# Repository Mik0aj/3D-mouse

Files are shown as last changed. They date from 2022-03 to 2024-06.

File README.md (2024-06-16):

# Synopsis

The aim of this project is to develop a prototype for a practical device designed to expedite the process of designing 3D models in CAD (Computer-Aided Design) software. The device is intended to allow users to freely rotate the camera across six axes. Commercial solutions currently available in the market are often expensive. The motivation behind this work is to create an affordable alternative that leverages easily accessible modules such as gyroscopes and accelerometers. To achieve movement across the XYZ axes, parametric plastic springs are utilized as compliant elements.
### Showcase video:
https://www.youtube.com/watch?v=9irIqQizjRs&t=3s

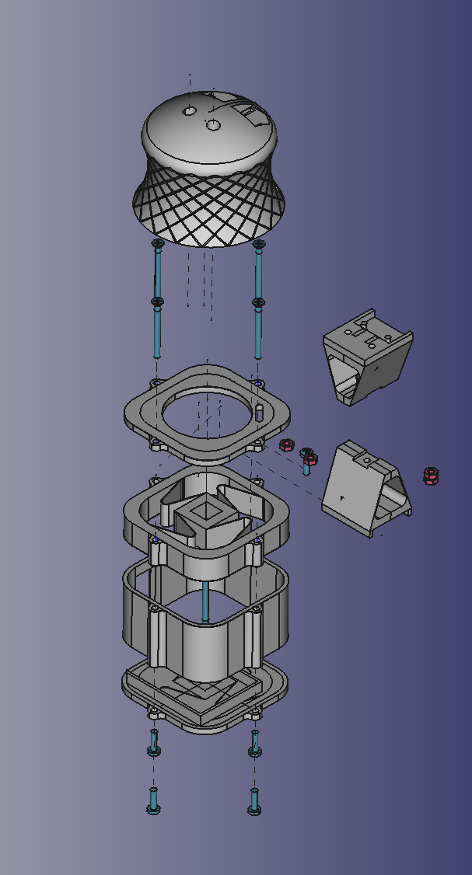
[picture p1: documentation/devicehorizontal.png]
"Exploaded view"


# Software 
## Design Patterns
Design patterns are best practices in software design aimed at enhancing code quality, efficiency, and reusability. This section outlines the design patterns utilized in this project, explaining their application to improve understanding. The implementations are based on references from established literature.

### Protothreads
Protothreads are lightweight, threads typically used in embedded systems where resources are limited, and multitasking is essential. Despite their simplicity, they provide effective concurrency in projects involving multiple sensors. Since the Arduino controller is single-threaded, protothreads simulate multitasking by sequentially executing code within a single thread using precise timing between function calls.

Usage in Project:

* protothreadMpuUpdate: Manages continuous reading of values from the gyroscope (MPU6050).
* protothreadJoystickBroadcast: Decides whether device should emulate a HID device in current moment.
* protothreadRGB: Provides visual feedback.
* protothreadPrintSerial: Displays key device parameters.
Each protothread interacts with an enum class Mode reference to determine the device's state and adjusts its behavior accordingly, similar to a Moore machine using switch statements.

### Adapter Pattern
The adapter pattern allows different libraries with varying interfaces to work together by converting incompatible interfaces into a compatible one. This is particularly useful in integrating different HID libraries that have different methods for similar functionalities.

Usage in Project:

* Created an interface JoystickEmulator.
* Developed adapters for XInput and Joystick libraries, enabling them to interact through a unified interface.
This pattern ensures flexibility in choosing the best library without necessitating significant code changes.

### Watchdog Pattern
The watchdog pattern enhances system reliability by monitoring the system for malfunctions and performing corrective actions like system resets if a failure is detected.

Usage in Project:

* Implemented a watchdog timer to monitor system health.
* Used deviceFailed() to handle errors, generate user feedback, and reset the device if necessary.
Error Codes:

* 1: Initialization failure of MPU6050.
* 2: Problem reading from the Digital Motion Processor (DMP).
* 10: State machine received an invalid value.
This mechanism helps maintain system stability by automatically recovering from failures.

These design patterns collectively improve the robustness, maintainability, and functionality of the device, ensuring it meets the project requirements effectively.

# Model creation
Whole project utilizes the FreeCad modeling software and various modules it provides such as:
* techdraw
* FEM
* Part Design
* Spreadsheet
* Assembly

## Parametric modeling

3D model parameterization in CAD software involves defining and controlling various parameters and properties of the model that affect its shape, size, proportions, appearance, and other characteristics. This allows for easy customization and modification of the model while maintaining its geometric and structural dependencies. Parameterization of 3D models in CAD software provides greater flexibility and control over the design. Changes to parameters can be easily implemented, and models can be adapted to different requirements. Parameterization also allows for automated generation of model variants and facilitates iterative design modifications, which can accelerate the prototyping process and increase work efficiency.

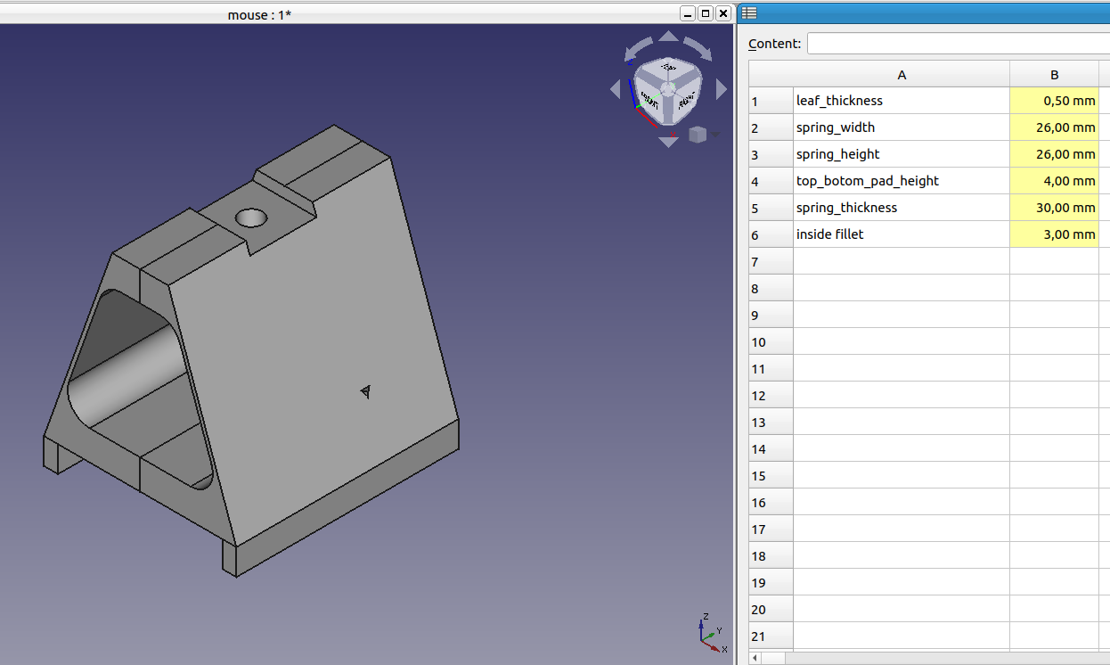
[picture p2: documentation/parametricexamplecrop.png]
"Parametric design"


## Fem simulations
The project utilizes Finite Element Method (FEM) simulations, performed using FreeCAD, to analyze and simulate the behavior of 3D models under various loads. FEM is a widely adopted numerical technique in engineering, used to model and analyze the behavior of different structures, including mechanical components. In this project, FEM is employed to verify the performance of compliant elements.

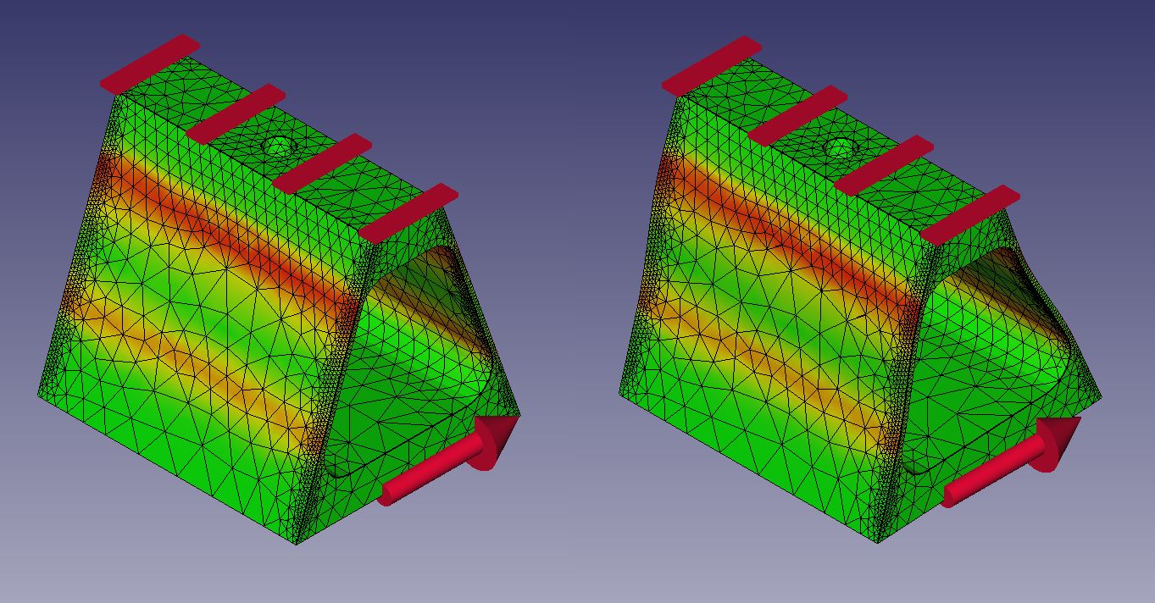
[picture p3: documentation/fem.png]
"FEM simulation"


## Hardware Components
* Arduino Pro Micro: This microcontroller board is based on the ATmega32u4 chip and is used to control the mouse's movements and buttons.
* MPU-6050 Sensor: This is a 6-axis gyro and accelerometer module that detects the device's orientation and acceleration.
* Two Buttons: These buttons are used to provide additional input to the device.

## 3D Printed Compliant Mechanisms:
These mechanisms are designed using springs that provide a tactile feedback to the user.
Software Components
The software for the 3D mouse is written in Arduino's programming language and is used to read the sensor data, control the device's movements, and process the button input.

## Setup and Usage
To use the 3D mouse, connect the Arduino Pro Micro and the MPU-6050 sensor to your computer. Then, upload the provided code to the Arduino board. The mouse can be used in any application that supports 6 DOF input, such as 3D modeling software or video games.

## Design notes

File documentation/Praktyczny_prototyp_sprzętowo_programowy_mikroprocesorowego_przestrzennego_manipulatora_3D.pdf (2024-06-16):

Uniwersytet Zielonogórski

Wydział Informatyki, Elektrotechniki i Automatyki

## Praca dyplomowa

## Kierunek: Informatyka

Praktyczny prototyp

sprzętowo-programowy

mikroprocesorowego przestrzennego

manipulatora 3D

## Mikołaj Mosoń

Promotor:
dr inż. Łukasz Hładowski

Zielona Góra, luty 2024

# Spis treści

1. Wstęp | 1
2. Implementacja | 3
3. Kontroler urządzenia | 20
4. Instrukcja obsługi | 23
5. Wnioski | 32

iv | Spis treści
A. Schematy urządzenia | 40

# Spis rysunków

2.1. Zrzut ekranu przedstawiajacy zastosowanie parametryczności w pro-
gramie FreeCAD | | 6
2.2. Zrzut ekranu przedstawiajacy symulacje FEM w programie FreeCAD. | 6
2.3. Poprawne dobranie parametrów wydruku | | 8
2.4. Niepoprawne dobranie parametrów wydruku | | 8
2.5. Zrzut ekranu przedstawiający najsłabsze punkty modelu, oraz przy-
kład brim | 8
2.6. Zrzut ekranu przedstawiający rezultat testów jednostkowych w VsCode. 19
4.1. Zrzut ekranu przedstawiający ułożenie sprężyn wewnątrz urządzenia
FreeCAD | 24
4.2. Zrzut ekranu przedstawiający w pełni rozłożone urządzenie w progra-
mie FreeCAD | 25
4.3. Krok pierwszy procesu składania urządzenia | 26
4.4. Krok drugi procesu składania urządzenia | 26
4.5. Krok trzeci procesu składania urządzenia | 27
4.6. Krok czwarty procesu składania urządzenia | 28
4.7. Krok piąty procesu składania urządzenia | 29
4.8. Krok szósty procesu składania urządzenia | 30
4.9. Schemat podłączenia urządzenia | 31

# Spis tabel

3.1. Porównanie Arduino Leonardo, STM32F103C8T6, ESP-WROOM-32
i Teensy-LC | 21

# Rozdział 1

# Wstęp

## 1.1. Cel i zakres pracy

Celem pracy jest opracowanie prototypu praktycznego urządzenia które, przyspieszy proces projektowania modeli 3D w programach typu CAD. Urządzenie ma za zadanie pozwolić użytkownikowi na swobodne obracanie kamerą w 6 osiach. Komercyjne rozwiązania dostępne aktualnie na rynku są drogie. Motywacją pracy jest stworzenie taniej alternatywy, która wykorzysta łatwo dostępne gotowe moduły żyroskopu i akcelerometru. Aby uzyskać ruch w osiach XYZ wykorzystane są elementy podatne w postaci parametrycznych plastikowych sprężyn.
Praca swym zakresem obejmuje:
- Opracowanie i praktyczne wykonanie układu elektronicznego dla manipulatora
- Opracowanie projektu i wykonanie modelu zewnętrznego dla manipulatora
- Projekt i implementacja oprogramowania umożliwiającego działanie urządzenia
- Wykonanie testów praktycznych opracowanego przyrządu

## 1.2. Analiza rynku

Rynek w tym przypadku to głównie zbiór klientów, którzy byliby zainteresowani wdrożeniem rozwiązania pozwalającego na zwiększenie komfortu oraz przyspieszenie projektowania w programach CAD. Możemy rozróżnić dwa główne typy klientów: klienci biznesowi, czyli centra inżynieryjne oraz klientów indywidualnych. Centra inżynieryjne - są to miejsca w których często projektuje się linie produkcyjne. Przykładem może być dostosowywanie paletek przewożących produkt na taśmociągu produkcyjnym. Klienci indywidualni - urządzenie mogłoby znaleźć swoje zastosowanie jako akcesorium dla freelancerów. Kolejną potencjalną grupą odbiorców indywidualnych byłyby osoby zajmujące się hobbistycznym modelowaniem 3D. Z racji zasady działania urządzeń takich jak joystick lub pad komputerowy, urządzenie mogłoby potencjalnie znaleźć swoje zastosowanie jako akcesorium dla graczy.

2 | Wstęp

## 1.3. Potrzeba biznesowa

| Obecnie rynek urządzeń wskazujących dla programów CAD zmonopolizowany
jest przez jedną firmę - 3Dconnexion. Inne urządzenia które byłyby w stanie wypełnić tę lukę wymagają skomplikowanej konfiguracji aby działać. Urządzenie opisywane w niniejszej pracy ma na celu stanowić tańszą alternatywę. Dodatkową zaletą jest bezproblemowa współpraca opracowanego narzędzia z systemem Linux. Należy podkreślić, iż rozwiązania opracowane przez firmę 3DConnection nie wspierają oficlajnie tego systemu.

## 1.4. Przegląd rozwiązań

Aktualnie na rynku dostępne są następujące typy urządzeń wejściowych:

| • Trackball[1] - urządzenie polegające na poruszaniu kulą zamiast poruszaniem
całym urządzeniem, jak w przypadku myszy.
| • Joystick[2], w zależności od modelu posiadają 2 lub 3 osie. Bez zewnętrznego
oprogramowania nie są wspierane przez oprogramowanie CAD.
| • 3DConnexion SpaceMouse[3] - to urządzenie do obsługi oprogramowania CAD, które umożliwia precyzyjne i sterowanie kursorami w aplikacjach 3D. Jest to

urządzenie typu "joystick" z 6-osiową kontrolą ruchów.

| • Steam controller[4] - urządzenie zaprojektowane z myślą o graniu na kom- puterze. Jednak oprogramowanie które jest do niego dołączone pozwala na skonfigurowanie go tak aby działał z każdą aplikacją. Posiada wbudowany

żyroskop oraz zestaw trackballi i joysticków.

# Rozdział 2

# Implementacja

## 2.1. Wykorzystane technologie

W tej sekcji zostaną omówione narzędzia, które zostały wykorzystane do realizacji projektu. Wśród tych narzędzi znajdują się m.in. oprogramowanie, drukarka 3D, komponenty elektroniczne, filament do drukarki oraz wiele innych. Wybór tych konkretnych narzędzi był wynikiem ich dostępności i przydatności w kontekście projektu oraz doświadczeniem przed rozpoczęciem projektu.

### 2.1.1. Oprogramowanie

- Arduino IDE[5] - narzędzie wykorzystywane w początkowej fazie projektu. Jednym z powodów wyboru Arduino IDE do programowania projektu było to, że jest to darmowe środowisko programistyczne. Ponadto, projekt wykorzystywał płytkę Arduino Leonardo, która była obsługiwana przez IDE. Ale wraz z rozwojem pojawiła się potrzeba bardziej zaawansowanych narzędzi do programowania i debugowania. W związku z tym środowisko programistyczne zostało zmienione.
- VsCode[6] - Wraz z rozwojem projektu podjęta została decyzja o zmianie środowiska programistycznego z Arduino IDE na VsCode. Rozważano również edytor tekstu NVIM, jednak pojawiły się problemy z konfiguracją serwera języków, aby był on kompatybilny z bibliotekami Arduino. Ostatecznie wybrano VsCode, ponieważ oferuje on większą funkcjonalność nie tracąc na prostocie użytkowania.
- PlatformIO[7] - to zaawansowane, open-source’owe środowisko programistyczne dla mikrokontrolerów, które umożliwia rozwijanie aplikacji dla różnych platform sprzętowych. Jest to uniwersalne narzędzie, które pozwala na pracę z różnymi platformami sprzętowymi, takimi jak Arduino, ESP8266, ESP32, STM32, oraz wiele innych. PlatformIO oferuje dostęp do tych samych bibliotek co Arduino IDE. Funkcje PlatformIO połączone wraz z frameworkiem Google Test pozwalają na testy jednostkowe oraz kompilację i weryfikacje części kodu na komputerze bez potrzeby przesyłania kodu na mikrokontroler.
- FreeCAD[8] - został wybrany do projektu z kilku powodów. Przede wszyst-

4 | Implementacja

kim, jest to darmowe oprogramowanie. Dodatkowo, FreeCAD posiada szereg narzędzi, które pozwalają na projektowanie modeli 3D oraz testowanie ich za pomocą metody FEM (Finite Element Method). Jednym z ważnych aspektów FreeCAD jest to, że modele, które się tworzy, mogą być parametryczne. Oznacza to, że po stworzeniu modelu, można go modyfikować, zmieniając wartości parametrów, takich jak długość, szerokość, wysokość itp. To bardzo przydatne na etapie prototypowania, pozwala to na osiągniecie wielu wariantów tego samego modelu. Ponadto, dzięki rozszerzeniom stworzonym przez społeczność, FreeCAD pozwala na składanie modeli w oprogramowaniu bez konieczności drukowania w celu sprawdzenia czy części do siebie pasują. Dzięki temu można zaoszczędzić czas i koszty związane z drukowaniem i testowaniem wielu wersji prototypu.

- Cura[9] - to darmowy, otwartoźródłowy program do przygotowywania plików do wydruku dla drukarek 3D. Dzięki Cura użytkownicy mogą dostosować ustawienia drukowania do swoich potrzeb, takie jak rozdzielczość, prędkość drukowania, ilość wypełnienia modelu i wiele innych. Cura oferuje także symulację druku, co pozwala na wczesne wykrywanie błędów i uniknięcie nieudanych prób drukowania. Sprawdzenie wyżej wymienionych parametrów jest krytycznie ważne w celu poprawnego wydruku elementów odkształcalnych.

### 2.1.2. Narzędzia

- Drukarka 3D tevo tornado[10] - wraz z zestawem części między innymi dyszami o różnych średnicach. Jest to drukarka typu FDM oparta na konstrukcji CR-10. W porównaniu do innych drukarek jak na przykład Prusa i3 MK3S lub Anycubic i3 Mega, Tevo Tornado posiada dużą przestrzeń roboczą o wymiarach 300 x 300 x 400 mm. Co z kolei niwelowało problem dzielenia modeli na mniejsze części oraz pozwalało na wydruk wielu modeli jednocześnie.
- Prusament PLA firmy Prusa Polymers[11] - wybór filamentu był kwestią bardzo ważną. Firma Prusa udostępnia parametry tego filamentu do pobrania[12], co pozwoliło na precyzyjne określenie jego właściwości i wykorzystanie ich w symulacjach numerycznych (FEM).

### 2.1.3. Biblioteki

- Google Test[13] - framework do testowania jednostkowego w języku C++, opracowany przez Google. Umożliwiający pisanie testów jednostkowych do weryfikacji poprawności zachowania kodu. Jest wyposażony w funkcje do odkrywania, wykonywania i raportowania wyników testów. Google Test wyposażone jest również w Google Mock (gmock). Pozwala to na prostsze testowanie skomplikowanych systemów, izolując poszczególne komponenty i sprawdzając ich interakcje z innymi częściami kodu.
- Spacenavd[14] - jest to sterownik umożliwiający komunikację pomiędzy urządzeniami typu myszy 3D a oprogramowaniem CAD. Jest w pełni kompatybilny z oprogramowaniem 3DConnexion, i jest jego darmową alternatywą. Oznacza

Modelowanie | 5

to że urządzenia współdziałające z tym sterownikiem powinny działać z ponad 200 programami wymienionymi na stronie 3DConnexion.

### 2.1.4. Elementy odkształcalne

Tradycyjnie aby uzyskać zakres ruchu w projektowanym urządzeniu stosowane są elementy sztywne (przykład stanowią zawiasy w drzwiach). Przeciwieństwem takich mechanizmów są elementy odkształcalne. Elementami odkształcalnymi są jednostki, które są częścią większej całości i są w stanie zmieniać swoje kształty i rozmiary w reakcji na siły mechaniczne, takie jak nacisk, rozciąganie lub skręcanie. Elementy odkształcalne są powszechnie stosowane w inżynierii i są istotne w projektowaniu i analizie konstrukcji, takich jak mosty, budynki, maszyny i sprzęt. Mogą być wykonane z różnych materiałów, takich jak stali, aluminium czy tworzywa sztuczne.

## 2.2. Modelowanie

W projekcie zastosowano technikę modelowania twardo powierzchniowego (z ang. hard surface) z parametryzacją modeli. Parametryzacja modeli 3D w programach CAD polega na definiowaniu i kontrolowaniu różnych parametrów i właściwości modelu, które wpływają na jego kształt, rozmiar, proporcje, wygląd i inne cechy. Pozwala to na łatwe dostosowywanie i modyfikowanie modelu, zachowując przy tym jego zależności geometryczne i konstrukcyjne. Dzięki parametryzacji modeli 3D w programach CAD uzyskuje się większą elastyczność i kontrolę nad projektem. Zmiany w parametrach mogą być łatwo wprowadzane, a modele mogą być dostosowywane do różnych wymagań. Parametryzacja pozwala również na automatyzację generowania wariantów modeli i ułatwia iteracyjne modyfikowanie projektu, co może przyspieszyć proces prototypowania i zwiększyć efektywność pracy. Sprężyny zostały wymodelowane na podstawie książki [15].
Dodatkową zaletą parametryzowanych sprężyn jest możliwość spersonalizowania urządzenia, dzięki czemu użytkownik może wybrać czy chce aby stawiały one mniejszy lub większy opór.

### 2.2.1. Symulacje FEM

Symulacje w oparciu o technikę elementów skończonych (Finite Element Method) w programie FreeCAD są narzędziem do analizy i symulacji zachowania modeli 3D pod wpływem obciążeń. FEM jest popularną metodą numeryczną wykorzystywaną w inżynierii do modelowania i analizy zachowania się różnych struktur, takich jak elementy mechaniczne. Metoda ta jest wykorzystywana w projekcie do sprawdzenia poprawności zachowania się elementów odkształcalnch. Moduł FEM, który umożliwia wygenerowanie odpowiedniej siatki modelu i przypisanie jej właściwości materiałowych. Właściwości materiałowe PLA zostały przypisane na podstawie parametrów technicznych podanych przez producenta filamentu[12].
Warto zwrócić uwagę że rys. 2.2 oraz 2.1 mogą wydawać się tym samym modelem. Jednakże do wykonania symulacji FEM wykorzystany został model uproszczony. Dla modelu ze zrzutu 2.1 możnaby wytworzyć siatkę potrzebną do symulacji ale trwałoby

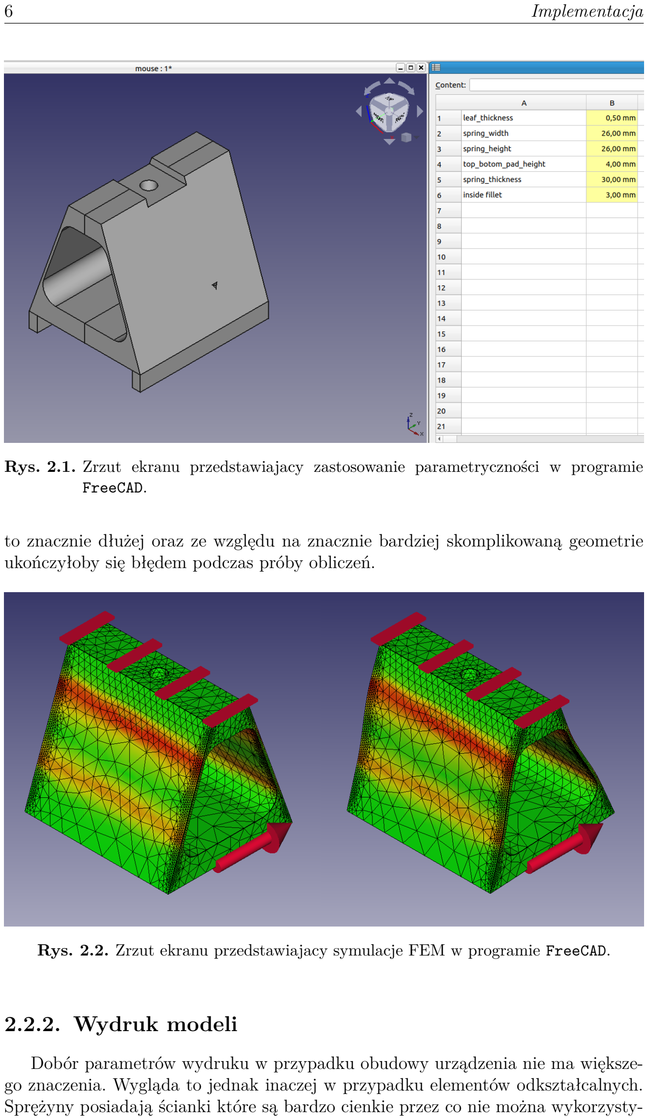
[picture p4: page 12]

6 | Implementacja

Rys. 2.1. Zrzut ekranu przedstawiajacy zastosowanie parametryczności w programie FreeCAD.

to znacznie dłużej oraz ze względu na znacznie bardziej skomplikowaną geometrie ukończyłoby się błędem podczas próby obliczeń.

Rys. 2.2. Zrzut ekranu przedstawiajacy symulacje FEM w programie FreeCAD.

### 2.2.2. Wydruk modeli

Dobór parametrów wydruku w przypadku obudowy urządzenia nie ma większego znaczenia. Wygląda to jednak inaczej w przypadku elementów odkształcalnych. Sprężyny posiadają ścianki które są bardzo cienkie przez co nie można wykorzysty-

Modelowanie | 7

wać ustawień takich jak brim. Brim to dodatkowa warstwa materiału na obrzeżach obiektu, która zapewnia lepszą przyczepność do stołu drukującego. Przykład zaznaczono kolorem niebieskim na rys. 2.5.
W celu utrzymania modelu w miejscu podczas wydruku najlepiej zastosować taśmę dwustronną lub klej. Rys. 2.3 przedstawia poprawnie wygenerowany g-code w programie cura. G-code jest to zestaw instrukcji które drukarka 3D musi wykonać w celu utworzenia modelu. Należy zwrócić uwagę że zewnętrzne cienkie ścianki sprężyny drukowane są jedną linią. Efekt ten można uzyskać dostosowując parametr leaf thickness widoczny na rys. 2.1 do szerokości linii wdruku. Najlepiej by te wartości były takie same jak średnica dyszy w drukarce 3D. Jest to najbardziej optymalne podejście do drukowania modelu ponieważ jest on wtedy najbardziej wytrzymały. Na rys. 2.3 oraz 2.5 widać białe punkty. Każda warstwa posiada dwa takie punkty i oznaczają one miejsce startowe oraz końcowe. W figurze z poprawnie dobranymi parametrami można zauważyć że punkty rozmieszczone są w losowy sposób. Losowość ta wraz z dodatkowym zastosowaniem zaokrąglenia (ang. fillet) wewnątrz modelu sprawia że wydruk jest wytrzymalszy niż to co zostałoby uzyskane w przypadku który widać na 2.5. Rys. 2.5 niemalże wszystkie punkty startowe w tym samym miejscu modelu. Podczas wydruku powoduje to nagromadzenie PLA w tych miejscach przez co ścianka sprężyny nie zawsze prawidłowo przylega poprawnie do reszty modelu. Staje się to najsłabszym miejscem uzyskanej bryły i w praktyce to będzie miejsce które pęknie jako pierwsze.
W przypadku rys. 2.4 w miejscu ścianki sprężyny wygenerowane zostało wypełnienie które widać za pomocą koloru pomarańczowego. Tak krótkie linie mają problem z adhezją do poprzednich warstw. Prowadzi to do niestabilności, słabej jakości wydruku oraz nierównomiernej ekstruzji plastiku. A w skrajnych przypadkach powoduje zacięcie się drukarki.
W celu zwiększenia komfortu gałka urządzenia posiada ergonomiczny kształt tak by użytkownik mógł ją wygodnie chwycić. Wygładzona powierzchnia urządzenia powoduje, że użytkownik ma trudności z pewnym chwytem. Potencjalnym rozwiązaniem jest zapożyczenie techniki wywodzącej się z obsługi tokarki zwaną radełkowaniem widoczną na zrzucie 4.2. Na gałce urządzenia został wytworzony wzór przypominający diamenty. Wytworzenie wzoru polega na ekstrudowaniu dwóch przecinających się linii i powielaniu wzoru z przesunięciem o kilka stopni. Jest to operacja bardzo wymagająca obliczeniowo dla komputera, i zajmuje więcej czasu w zależności od ilości powtórzeń. Ponieważ FreeCAD przy każdej modyfikacji modelu ponownie przelicza wszystkie kroki tą operacje najlepiej zastosować na samym końcu hierarchii. W przeciwnym razie najmniejsza nawet zmiana może potrwać do kilku minut.

### 2.2.3. Problem nazewnictwa topologicznego

Problem z nazewnictwem topologicznym w programie FreeCAD polega na tym, gdy po wprowadzeniu zmian w obiekcie, takie jak wyciągnięcie, wycięcie, połączenie itp., wewnętrzna nazwa kształtu może ulec zmianie. Ta zmiana może wpłynąć na inne parametryczne właściwości zależne od tego kształtu. Skutkiem tego błędu może być na przykład przypisanie szkicu do innej ściany. Jest to zjawisko który dotyczy wszystkich modeli tworzonych za pomocą programu FreeCAD. Problem można zniwelować stosując odpowiednie techniki omówione w dokumentacji programu [16].

8 | Implementacja

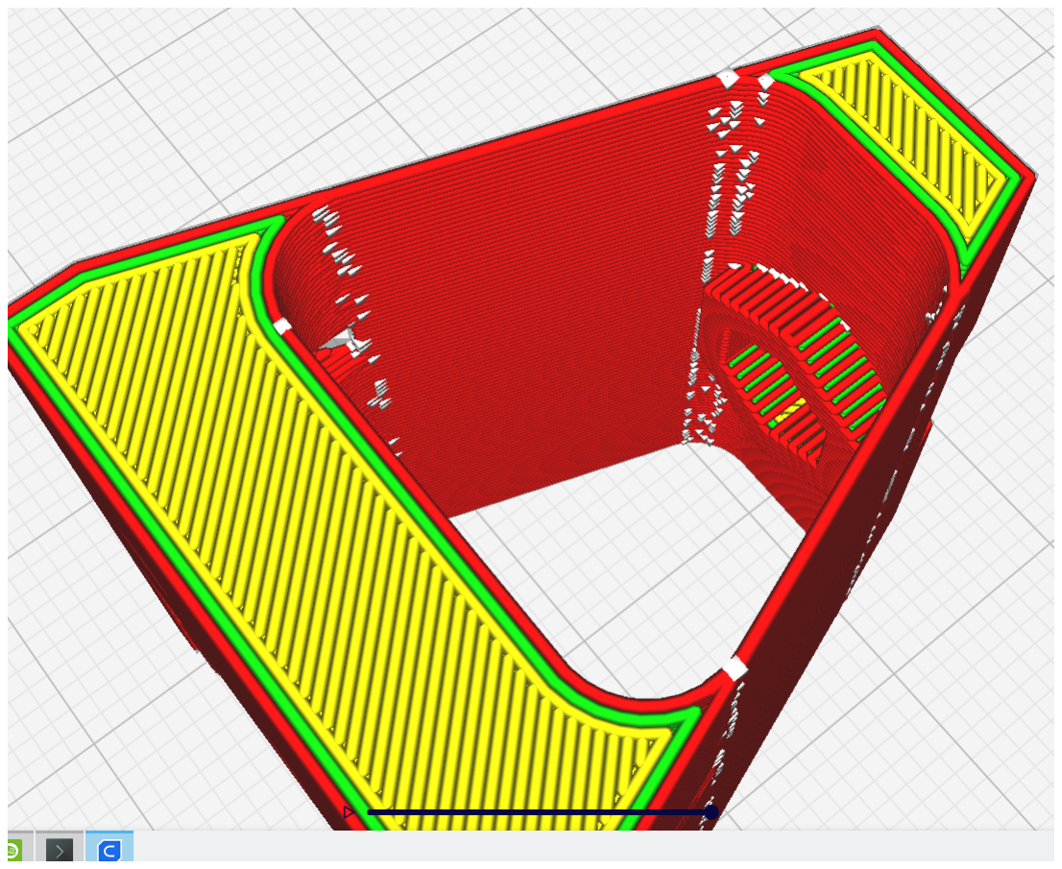
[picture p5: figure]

Rys. 2.3. Poprawne dobranie parametrów wydruku.

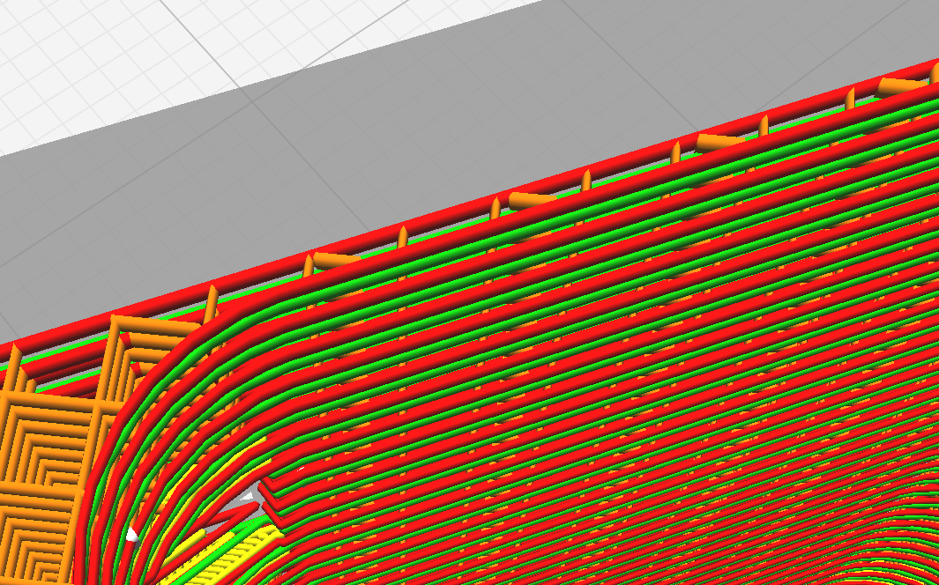
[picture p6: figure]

Rys. 2.4. Niepoprawne dobranie parametrów wydruku.

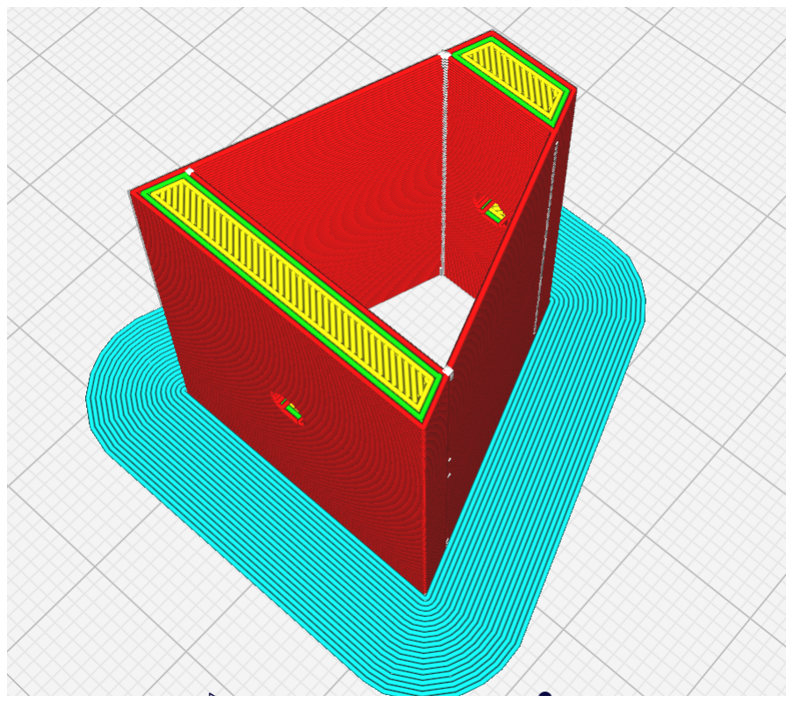
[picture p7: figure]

Rys. 2.5. Zrzut ekranu przedstawiający najsłabsze punkty modelu, oraz przykład brim.

Wzorce projektowe | 9

## 2.3. Wzorce projektowe

Wzorce projektowe są uważane za najlepsze praktyki projektowania, które mają na celu zwiększenie jakości, wydajności i ponownego wykorzystywania kodu źródłowego.
W tej sekcji zostaną przedstawione wybrane wzorce projektowe wykorzystane w ramach realizacji projektu. Przedstawione zostaną opisy i przykłady zastosowań tych wzorców w celu zwiększenia zrozumienia ich roli. Wykorzystane w pracy implementacje wzorców projektowych bazują na książkach [17] i [18].

### 2.3.1. Protowątki

Protowątki są zwykle używane w systemach wbudowanych, gdzie zasoby są ograniczone, a wymagane jest jednoczesne wykonywanie wielu zadań. Dzięki prostocie i efektywności, są często stosowane w projektach do obsługi urządzeń wielu sensorów. Arduino jest kontrolerem jednoprocesorowym i jednowątkowym. Oznacza to że jedynym sposobem na uzyskanie złudzenia wielozadaniowości jest zastosowanie protowątków.
Protowątki opierają się na technice opakowywania kodu w funkcje, które mogą być wykonywane sekwencyjnie w ramach jednego wątku. Działają one dzięki precyzyjnemu odmierzaniu czasu jaki upłynął pomiędzy kolejnymi wykonaniami funkcji. W celu zwiększenia czytelności kodu jeden wątek zajmuje się tylko jednym zadaniem. W projekcie zostały zastosowane 4 protowątki:
- protothreadMpuUpdate - odpowiedzialny za kolejne odczytywanie wartości z czujnika żyroskopu (MPU6050),
- protothreadJoystickBroadcast - stosowany za emulację urządzenia HID,
- protothreadRGB - wątek zastosowany w celu wizualnej informacji zwrotnej,
- protothreadPrintSerial - jest to wątek który wyświetla najważniejsze parametry urządzenia,

Do każdego z protowątków za pomocą referencji przekazywane są obiekty enum klasy Mode lst. 2.1. Jest to referencja typu const ponieważ wątki jedynie odczytują stan w jakim urządzenie aktualnie się znajduje.

1 | enum c l a s s Mode
2 | {
3 | XYZ,
4 | rXrYrZ ,
5 | BROADCASTING,
6 | NOT_BROADCASTING,
7 | } ;

Listing 2.1. Implementacja stanów w których urządzenie może sie znaleźć

Następnie na wzór automatu Moore’a (tzn kolejne stany urządzenia nie są zależne od poprzednich) dany protowątek za pomocą instrukcji switch decyduje jak powinien się zachować.

Implementacja

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

}
| PT_END(&protoThread ) ;

}

Listing 2.2. Protowątek odpowiedzialny za obsługę MPU6050

Funkcja na listingu 2.2 zajmuje się obsługą żyroskopu i akcelerometru. Urządzenie nieustannie zapisuje dane z żyroskopu i zapisuje je do dwukierunkowej kolejki. Gdy urządzenie nie znajduje się w trybie nadawania wartości te zapisywane są jako offsety. Ta potrzeba wynika z tego że gdy użytkownik obróci urządzenie gdy to nie znajduje się w trybie nadawania, wyniki będą przekłamane. Urządzenie musi się samo skorygować aby wysyłać poprawne sygnały. Dlatego wartości pomniejszane są o offsety i zapisywane do kontenera deviceValues, który wykorzystany wykorzystany
| jest w innych protowątkach 2.3.

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

Wzorce projektowe | 11
4 | PT_BEGIN(&protoThread ) ;
5 | w hil e ( 1 )
6 | {
7 | J o y s ti c k B r o a d c a s t = m i l l i s ( ) ;
8 | PT_WAIT_UNTIL(&protoThread , m i l l i s ( ) − J o y s ti c k B r o a d c a s t >
| JOYSTICK_THREAD_TIMER) ;
9 | swi t c h ( broadcastMode )
10 | {
11 | c a s e Mode : : BROADCASTING:
12 | f o r ( i n t s e t t e r I n d e x { 0 }; s e t t e r I n d e x < 3 ; s e t t e r I n d e x++)
13 | {
14 | auto v al = d e vi c eV al u e s . a t ( s e t t e r I n d e x ) ∗ 1 0 0;
15 | swi t c h ( deviceMode )
16 | {
17 | c a s e Mode : : XYZ:
18 | j o y s t i c k . setXYZ ( s e t t e r I n d e x , v al ) ;
19 | break ;
20 | c a s e Mode : : rXrYrZ :
21 | j o y s t i c k . setRXRYRZ( s e t t e r I n d e x , v al ) ;
22 | break ;
23 | d e f a u l t :
24 | S e r i a l . p r i n t ( "Wrong mode chceck : " ) ;
25 | S e r i a l . p r i n t (__LINE__) ;
26 | d e v i c e F ail e d ( 1 0 ) ;
27 | break ;
28 | }
29 | j o y s t i c k . send ( ) ;
30 | }
31 | break ;
32 | c a s e Mode : :NOT_BROADCASTING:
33 | break ;
34 | d e f a u l t :
35 | S e r i a l . p r i n t ( "Wrong mode chceck : " ) ;
36 | S e r i a l . p r i n t (__LINE__) ;
37 | d e v i c e F ail e d ( 1 0 ) ;
38 | break ;
39 | }
40 | }
41 | PT_END(&protoThread ) ;
42 | }
| Listing 2.3. Przykład maszyny stanów w protowątku JoystickBroadcast
| Funkcja na listingu 2.3 jest odpowiedzialna za nadawanie danych z urządzenia joy-
| stick przez określony czas zgodnie z aktualnym trybem pracy. W przypadku, gdy
| aktualnym trybem pracy jest BROADCASTING, funkcja iteruje po każdym elemencie
| tablicy wartości z urządzenia, mnoży ją przez 100, aby zmienić zakres wartości, a
| następnie przesyła wartości na zewnętrzny interfejs przez odpowiednie wywołania
| funkcji joystick.setXYZ() lub joystick.setRXRYRZ() i joystick.send().
| W przypadku, gdy aktualnym tryb pracy jest "NOT_BROADCASTING", funk-
| cja nic nie robi. Funkcja kończy się po skończeniu pętli while, a protokół wątku

Implementacja

wykorzystuje makro "PT_END" do zakończenia wykonywania wątku.

### 2.3.2. Wzorzec adapter

Istnieje wiele bibliotek emulujących urządzenia HID. Mimo że większość z nich w wielu przypadkach wykonuje te same czynności ich interfejsy różnią się od siebie jak wskazano na listingu 2.4.

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

Listing 2.4. Obie metody setXAxis oraz setJoystickX odpowiadają za to samo zadanie mianowicie ustawianie wartości osi X.

Utrudnia to znalezienie biblioteki która okazałaby się najlepszym rozwiązaniem ponieważ każda nowa biblioteka wymagałaby drastycznych zmian w kodzie. Ten problem można jednak zniwelować stosując wzorzec projektowy adaptera. Na potrzeby głównej pętli został napisany interfejs do którego wykonano adaptery dla bibliotek XInput oraz Joystick.

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

{
p u bli c :
v i r t u a l v oid setXAxisRange ( i n t MIN_X, i n t MAX_X) = 0 ; . . .

} ;

/// Zawartosc J o y s ti c kLi b r a r yA d a p t e r . h

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

{
j o y s t i c k −>setXAxisRange (MIN_X, MAX_X) ;

}

} ;

/// Zawartosc J o y s ti c kLi b r a r yA d a p t e r . h

c l a s s XInputAdapter : p u bli c J o y s ti c kEm ul a t o r

{
X I n p u t I n t e r f a c e ∗XInput ;

Wzorce projektowe | 13

32
33 | p u bli c :
34 | . . .
35 | v oid setXAxisRange ( i n t MIN_X, i n t MAX_X)
36 | {
37 | XInput−>setRange (JOY_LEFT, MIN_X, MAX_X) ;
38 | }
39 | . . .
40 | } ;

41
42 | #e n d i f // XINPUT_ADAPTER
| Listing 2.5. Zastosowanie wzorca adaptera na przykładzie metody setXAxisRange
| Przed przystąpieniem do procesu wgrywania oprogramowania na płytce, należy
| wybrać adapter. W miejscu deklaracji adaptera należy od komentować odpowiednią
| sekcję kodu 2.6. Linijka 4 przypisuje obiekt klasy podrzędnej JoystickLibraryAdapter
| do referencji klasy nadrzędnej JoystickEmulator. Ponieważ JoystickEmulator jest
| interfejsem abstrakcyjnym, nie można utworzyć jego instancji. Można jednak użyć go
| jako referencji lub wskaźnika do obiektu konkretnej klasy implementującej interfejs,
| takiej jak JoystickLibraryAdapter lub XInputAdapter.
| Należy w tym miejscu zwrócić uwagę, że && oznacza referencję rvalue, która w
| tym kontekście jest używana do powiązania z tymczasowym obiektem zwracanym
| przez konstruktor JoystickLibraryAdapter. Wydłuża to czas życia obiektu tym-
| czasowego do końca bieżącego zakresu, zapewniając, że obiekt pozostanie ważny do
| użycia przez referencję joysticka.
| Jest to część polimorfizmu, gdzie wskaźnik lub referencja klasy bazowej może być
| użyta do wywołania metod zaimplementowanych przez dowolną klasę pochodną.
1 | #i n cl u d e <XInputAdapter . h>
2 | #i n cl u d e <XInput . h>
3 | X I n p u tC o n t r oll e r x ;
4 | J o y s ti c kEm ul a t o r &&j o y s t i c k = XInputAdapter ( x ) ;
| Listing 2.6. Wybór adaptera.

### 2.3.3. Wzorzec watchdog

| Systemy niezależnie od swojej skali i zaawansowania, skazane są na błędy. Wyni-
| ka to z faktu, że każdy system jest złożony z wielu elementów, które mogą wpływać
| na siebie nawzajem, a także zależeć od otoczenia i warunków, w których działa-
| ją. W celu zapewnienia niezawodności systemów wbudowanych stosuje się mecha-
| nizm watchdog. Jego zadaniem jest monitorowanie pracy systemu i w razie wykrycia
| awarii automatycznie przerywanie jego pracy lub wykonywanie określonych działań
| awaryjnych, takich jak restart systemu.
1 | #i n cl u d e <avr /wdt . h>

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

14 | Implementacja
6 | // 1 = i n i t i a l memory l o a d f a i l e d
7 | // 2 = DMP c o n f i g u r a t i o n upd a te s f a i l e d
8 | // 10 = Wrong mode d e t e c t e d
9 | w hil e ( 1 )
10 | {
11 | S e r i a l . p r i n t (F( " Device f a i l e d ( code " ) ) ;
12 | S e r i a l . p r i n t ( code ) ;
13 | S e r i a l . p r i n t l n (F( " ) " ) ) ;
14 | d el a y ( 1 0 0 0 ) ;
15 | an al o gW ri te (RED_PIN, 2 5 5 ) ;
16 | d el a y ( 1 0 0 0 ) ;
17 | an al o gW ri te (RED_PIN, 0 ) ;
18 | }
19 | }

20
21 | v oid s e tup ( )
22 | {
23 | . . .
24 | wdt_enable (WDTO_4S) ;
25 | S e r i a l . p r i n t l n (F( " I n i t i a l i z i n g I2C d e v i c e s . . . " ) ) ;
26 | mpu. i n i t i a l i z e ( ) ;
27 | de vS t a tu s = mpu. d m p I n i t i a l i z e ( ) ;
28 | S e r i a l . p r i n t l n ( de vS t a tu s ) ;
29 | i f ( de vS t a tu s != 0 )
30 | {
31 | d e vi c e F ail e d ( de vS t a tu s ) ;
32 | }
33 | . . .
34 | }

35
36 | v oid l o o p ( )
37 | {
38 | wdt_reset ( ) ;
39 | . . .
40 | }
| Listing 2.7. Zastosowanie mechanizmu watchdog
| Funkcja deviceFailed() na listingu 2.7 generuje informacje zwrotną dla użyt-
| kownika gdy wystąpi błąd. Dioda LED urządzenia zacznie migać na czerwono oraz
| wyświetli na porcie Serial informacje z kodem błędu. Wykonując tą funkcję urzą-
| dzenie wpada w nieskończoną pętle przez co wdt_reset() nie zostanie wywołane
| skutkując resetem urządzenia. Opracowane na potrzeby pracy urządzenie zostało
| skonfigurowane tak, aby w przypadku błędu zwracało jeden z poniższych kodów:
| • 1, kod informuje o tym że nie udało się zainicjalizować MPU6050,
| • 2, kod informuje o tym że wystąpił problem z odczytem informacji z DMP
| (Digital Motion Processor),
| • 10 kod informuje o tym że maszyna stanów otrzymała niepoprawną wartość,

Porównanie bibliotek HID | 15

Autorka książki [17] zaleca wyłączenie funkcji watchdog podczas debuggowania z wykorzystaniem debbugera hardwareowego, w celu uniknięcia niespodziewanego zachowania.

## 2.4. Porównanie bibliotek HID

Wśród bibliotek HID dostępnych dla Arduino najodpowiedniesze i najbardziej dopracowane wydają się być XInput oraz Joystick. Realizują podobne do siebie funkcjonalności. Mają jednak znaczące różnice w tej sekcji zostaną one omówione.

### 2.4.1. Joystick

Biblioteka Joystick była w pierwszej kolejności brana pod uwagę przy projektowaniu urządzenia. Na jej bazie był zaprojektowany jest interfejs dla wzorca projektowego adapter. Pozwala ona na emulację szerokiej gamy sygnałów wejściowych:

- 32 przyciski,
- joystick osie - X, Y, Z (16 bitowa precyzja),
- joystick osie rotacji - X, Y, Z (16 bitowa precyzja),
- pedał steru (16 bitowa precyzja),
- pedał gazu (16 bitowa precyzja),
- przepustnica (16 bitowa precyzja),
- pedał hamulca (16 bitowa precyzja),
- kierownica analogowa (16 bitowa precyzja),

W przypadku gier pojawiają się problemy jeżeli chodzi o poprawne wykrywanie urządzenia które wykorzystuje tę bibliotekę. Po zainstalowaniu sterowników i ich odpowiedniej konfiguracji urządzenie będzie natomiast widziane przez wszystkie programy CAD które obsługują myszy 3D. Biblioteka jest oparta na licencji LGPL-3.0, pozwala ona na to aby urządzenie zostało wykorzystane komercyjnie.

### 2.4.2. XInput

XInput jest bez problemu wykrywany przez wszystkie gry wspierające XInput Microsoftu. Jeżeli chodzi o programy typu CAD, to domyślnie nie wspierają padów XInput. Ponieważ urządzenia XInput nie są kompatybilne z Spacenavd oznacza to że w zależności od programu trzeba szukać odpowiednich rozszerzeń. XInput nie może być zastosowany komercyjnie ponieważ stosuje rozwiązania Microsoftu USB VID i PID. Bez VID/PID sterowniki ignorują urządzenie i nie będzie ono wykorzystane jako kontroler[19]. XInput pozwala na emulacje:

- 10+1 przycisków,

16 | Implementacja
- 2 joysticków analogowych (16 bitowa precyzja),
- 2 triggery analogowe (8 bitowa precyzja),
- 1 czterokierunkowy D-Pad.

Programowanie z wykorzystaniem XInput jest niewygodne. Sama biblioteka działa domyślnie w trybie debug, to jest wyświetla przez interfejs szeregowy Serial wartości które urządzenie powinno nadawać. Żeby nie działać w trybie debug trzeba wykorzystać XInput USB Core for Arduino AVR. Korzystanie z tego projektu znacznie komplikuje dalszy rozwój, ponieważ każdorazowa aktualizacja oprogramowania wymaga całkowitego resetu płytki. Warto jeszcze zwrócić uwagę że wykorzystania tej biblioteki urządzenie nie zostanie nigdy poprawnie rozpoznane przez konsole Microsoftu[19], ponieważ układ nie posiada odpowiedniego chipu. Mimo że XInput pozwala na 6 wejść analogowych to realnie do tego projektu można wykorzystać jedynie 4 wejścia czyli oba joysticki. Triggery natomast nie nadają sie do wykorzystania.

## 2.5. Testowanie bibliotek HID

Jako framework testujący brane pod uwagę biblioteki Google Test, ArduinoUnit oraz Unity[20]. Dwa ostatne frameworki pozwalają na testowanie bezpośrednio na Arduino. Są one znacznie mniej popularne niż Google Test. Warto również dodać że nazwa Unity pokrywa się z silnikiem do gier o takiej samej nazwie. Znacznie utrudnia to znalezienie informacji o tej bibliotece. W ostateczności zdecydowano na wykorzystanie Google Test. Jest to najczęściej wykorzystywane narzędzie do pisania testów. Jego największą zaletą jest możliwość korzystania z Google Mock.
W celu zapewnienia poprawności działania metod, stworzono testy jednostkowe. Użycie Google Mock umożliwiło testowanie funkcji bez konieczności podłączania płytki do komputera, co znacząco przyspieszyło proces pisania kodu. Dzięki temu podejściu możliwe było skoncentrowanie się na testowaniu poszczególnych funkcji bez konieczności manualnego sprawdzania na fizycznym sprzęcie.

### 2.5.1. Wykorzystanie GMock

Listing 2.8 przedstawia przykład zastosowania biblioteki Google Mock dla biblioteki Joystick. Utworzono klasę JoystickMock, która dziedziczy po interfejsie JoystickInterface. W klasie JoystickMock zdefiniowano szereg metod, które są symulowane za pomocą makr MOCK_METHOD. Te makra pozwalają na definiowanie metod w klasach mock w sposób deklaratywny, bez konieczności dostarczania ciała tych metod. Makro MOCK_METHOD przyjmuje zwracany typ, nazwę metody oraz parametry. Następnie generowany jest kod, który tworzy symulowaną implementację metody w klasie mock, co pozwala na kontrolowanie zachowania tych metod podczas testów. Analogiczna klasa mock jaką widać na listingu 2.8 została utworzona dla biblioteki XInput.

1 | #i f n d e f JOYSTICK_MOCK
2 | #d e f i n e JOYSTICK_MOCK
3 | #i n cl u d e <gmock/gmock . h>

Testowanie bibliotek HID | 17
4 | #i n cl u d e <mocks / J o y s t i c k I n t e r f a c e . h>

5
6 | c l a s s JoystickMock : p u bli c J o y s t i c k I n t e r f a c e
7 | {
8 | p u bli c :
9 | MOCK_METHOD( void , begin , ( b o ol i ni tA u t o S e n d S t a t e ) , ( o v e r r i d e
| ) ) ;
10 | MOCK_METHOD( void , end , ( ) , ( o v e r r i d e ) ) ;
11 | MOCK_METHOD( void , p re s sBu t t on , ( uin t8_ t button ) ) ;
12 | MOCK_METHOD( void , r el e a s e B u t t o n , ( uin t8_ t button ) , ( o v e r r i d e
| ) ) ;
13 | MOCK_METHOD( void , sendS t a te , ( ) , ( o v e r r i d e ) ) ;
14 | MOCK_METHOD( void , s e t A c c el e r a t o r , ( in t 3 2_ t v al u e ) , ( o v e r r i d e
| ) ) ;
15 | MOCK_METHOD( void , se tB r ake , ( in t 3 2_ t v al u e ) , ( o v e r r i d e ) ) ;
16 | MOCK_METHOD( void , se tBu t ton , ( uin t8_ t button , uin t8_ t v al u e )
| , ( o v e r r i d e ) ) ;
17 | MOCK_METHOD( void , se tH a tSwi tch , ( in t 8_ t hatSwitch , in t 1 6_ t
| v al u e ) , ( o v e r r i d e ) ) ;
18 | MOCK_METHOD( void , setRudder , ( in t 3 2_ t v al u e ) , ( o v e r r i d e ) ) ;
19 | MOCK_METHOD( void , setXAxis , ( in t 3 2_ t v al u e ) , ( o v e r r i d e ) ) ;
20 | MOCK_METHOD( void , setYAxis , ( in t 3 2_ t v al u e ) , ( o v e r r i d e ) ) ;
21 | MOCK_METHOD( void , se tZAxi s , ( in t 3 2_ t v al u e ) , ( o v e r r i d e ) ) ;
22 | MOCK_METHOD( void , setRxAxis , ( in t 3 2_ t v al u e ) , ( o v e r r i d e ) ) ;
23 | MOCK_METHOD( void , setRyAxis , ( in t 3 2_ t v al u e ) , ( o v e r r i d e ) ) ;
24 | MOCK_METHOD( void , setRzAxis , ( in t 3 2_ t v al u e ) , ( o v e r r i d e ) ) ;
25 | MOCK_METHOD( void , setRxAxisRange , ( in t 3 2_ t MIN_X, in t 3 2_ t
| MAX_X) , ( o v e r r i d e ) ) ;
26 | MOCK_METHOD( void , setRyAxisRange , ( in t 3 2_ t MIN_Y, in t 3 2_ t
| MAX_Y) , ( o v e r r i d e ) ) ;
27 | MOCK_METHOD( void , setRzAxisRange , ( in t 3 2_ t MIN_Z, in t 3 2_ t
| MAX_Z) , ( o v e r r i d e ) ) ;
28 | MOCK_METHOD( void , setXAxisRange , ( in t 3 2_ t MIN_X, in t 3 2_ t
| MAX_X) , ( o v e r r i d e ) ) ;
29 | MOCK_METHOD( void , setYAxisRange , ( in t 3 2_ t MIN_Y, in t 3 2_ t
| MAX_Y) , ( o v e r r i d e ) ) ;
30 | MOCK_METHOD( void , setZAxisRange , ( in t 3 2_ t MIN_Z, in t 3 2_ t
| MAX_Z) , ( o v e r r i d e ) ) ;
31 | MOCK_METHOD( void , s e t S t e e r i n g , ( in t 3 2_ t v al u e ) , ( o v e r r i d e ) ) ;
32 | MOCK_METHOD( void , s e t T h r o t tl e , ( in t 3 2_ t v al u e ) , ( o v e r r i d e ) ) ;
33 | } ;

34
35 | #e n d i f // JOYSTICK_MOCK
| Listing 2.8. Przykład zastosowania gmock dla biblioteki Joystick.

### 2.5.2. Testy jednostkowe

| Makro TEST jest podstawowym elementem frameworka do testowania opro-
| gramowania w Google Test. Służy do definiowania testów jednostkowych. Makro
| przyjmuje nazwę grupy testów oraz nazwę samego testu. Grupowanie testów jest

18 | Implementacja

wskazane w celu zachowania porządku. W projekcie przyjęto podejście, w którym stosuje się jak najbardziej opisowe nazwy dla testów.

1 | . . .
2 | TEST( J o y s ti c kLi b r a r yA d a p t e rT e s t s ,
| ProperMethodsBeingInvokedInSetXYZ )
3 | {
4 | JoystickMock j ;
5 | J o y s ti c kEm ul a t o r &&j o y s t i c k = J o y s ti c kLi b r a r yA d a p t e r ( j ) ;
6 | c o n s t e x p r i n t axisCoun t { 3 };
7 | EXPECT_CALL( j , se tXAxis ( 0 ) ) . Times ( t e s t i n g : : AtLeast ( 1 ) ) ;
8 | EXPECT_CALL( j , se tYAxis ( 0 ) ) . Times ( t e s t i n g : : AtLeast ( 1 ) ) ;
9 | EXPECT_CALL( j , s e tZA xi s ( 0 ) ) . Times ( t e s t i n g : : AtLeast ( 1 ) ) ;
10 | f o r ( si z e _ t a x i s = 0 ; a x i s < axisCoun t ; a x i s++)
11 | {
12 | j o y s t i c k . setXYZ ( a xi s , 0 ) ;
13 | }
14 | }

15
16 | TEST( J o y s ti c kLi b r a r yA d a p t e rT e s t s ,
| ProperMethodsBeingInvokedInSetRXRYRZ )
17 | {
18 | JoystickMock j ;
19 | J o y s ti c kEm ul a t o r &&j o y s t i c k = J o y s ti c kLi b r a r yA d a p t e r ( j ) ;
20 | c o n s t e x p r i n t axisCoun t { 3 };
21 | EXPECT_CALL( j , setRxAxis ( 0 ) ) . Times ( t e s t i n g : : AtLeast ( 1 ) ) ;
22 | EXPECT_CALL( j , setRyAxis ( 0 ) ) . Times ( t e s t i n g : : AtLeast ( 1 ) ) ;
23 | EXPECT_CALL( j , se tRzAxi s ( 0 ) ) . Times ( t e s t i n g : : AtLeast ( 1 ) ) ;
24 | f o r ( si z e _ t a x i s = 0 ; a x i s < axisCoun t ; a x i s++)
25 | {
26 | j o y s t i c k . setRXRYRZ( a xi s , 0 ) ;
27 | }
28 | }

29
30 | TEST( J o y s ti c kLi b r a r yA d a p t e rT e s t s ,
| ProperMethodsBeingInvoked InSend )
31 | {
32 | JoystickMock j ;
33 | J o y s ti c kEm ul a t o r &&j o y s t i c k = J o y s ti c kLi b r a r yA d a p t e r ( j ) ;
34 | EXPECT_CALL( j , s e n d S t a t e ( ) ) . Times ( t e s t i n g : : AtLeast ( 1 ) ) ;
35 | j o y s t i c k . send ( ) ;
36 | }
37 | . . .
| Listing 2.9. Przykładowe testy jednostkowe.
| W listingu 2.9 przedstawiono kod napisany na potrzeby testowania klasy
| JoystickLibraryAdapter. Każdy z testów przyjmuje obiekty typu mock na którym
| będzie sprawdzane poprawne wywoływanie metod. Makro EXPECT_CALL przyjmuje
| wspomniany mock, nazwę odpowiedniej metody oraz oczekiwaną ilość wywołań.

Testowanie bibliotek HID | 19

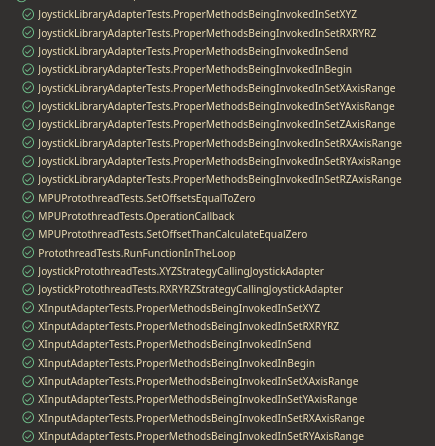
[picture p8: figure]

Rys. 2.6. Zrzut ekranu przedstawiający rezultat testów jednostkowych w VsCode.

Rysunek 2.6 przedstawia rezultat wszystkich testów stworzonych do projektu. Jednak nie wszystkie zaimplementowane klasy zostały ostatecznie wykorzystane. Klasy do których powstały testy jednostkowe a które nie zostały wykorzystane zostaną omówione w sekcji dotyczącej dalszego rozwoju projektu.

# Rozdział 3

# Kontroler urządzenia

## 3.1. Mikrokontroler

Jedną z najważniejszych decyzji podczas projektowania urządzenia jest wybór odpowiedniego mikrokontrolera. To, który mikrokontroler zostanie wybrany, ma wpływ na potencjalne możliwości i sposób komunikacji z komputerem.
Na rynku dostępnych jest wiele gotowych rozwiązań dla małych, wydajnych jednostek obliczeniowych, począwszy od prostych platform takich jak Arduino Leonardo, opartych na procesorach Atmel ATmega[21], aż po znacznie szybsze i wydajniejsze mikrokontrolery, takie jak Teensy LC[22] z procesorem ARM Cortex[23] na pokładzie. Tabela 3.1 przedstawia porównanie mikrokontrolerów które były brane pod uwagę.
Szukany kontroler powinien posiadać:
- możliwość emulacji urządzenia HID,
- obsługiwać magistralę I2C,
- możliwie mały rozmiar.

Mikrokontroler | 21
Parametr | Arduino Le-onardo | STM32 blue pill | ESP-WROOM-32 | Teensy-LC
Mikrokontroler | ATmega32u4 | STM32F103C8T6 | ESP32 | MKL26Z64
Architektura | AVR | ARM Cortex-M3 | Xtensa LX6 | ARM Cortex-M0+
Zegar | 16 MHz | 72 MHz | 240 MHz | 48 MHz
Pamięć Flash | 32 KB | 64 KB | 4 MB | 256 KB
Pamięć RAM | 2.5 KB | 20 KB | 520 KB | 32 KB
Ilość pinów cy-frowych | 20 | 37 | 26 | 27
Ilość pinów analogowych | 12 | 10 | 18 | 13
Komunikacja | USB, UART, SPI, I2C | UART, SPI, I2C | Wi-Fi, Bluetooth, UART, SPI, I2C | USB, UART, SPI, I2C

Tab. 3.1. Porównanie Arduino Leonardo, STM32F103C8T6, ESP-WROOM-32 i Teensy-LC

Po rozważeniu różnych opcji, w tym Arduino Leonardo, STM32, ESP32 i Teensy LC, ostatecznie wybrano Arduino Leonardo. Wybór ten opiera się na tym, że Arduino Leonardo spełnia powyższe wymagania, a ponadto jest bardzo popularnym rozwiązaniem, co ułatwia znalezienie informacji na jego temat. Mimo relatywnie małych możliwości względem konkurencji Arduino Leonardo nie ma problemów z osiągnięciem założeń projektu.
Zastosowanie ESP32 wydaje się być nieuzasadnione, ponieważ projekt nie wykorzystałby w pełni potencjału tej płytki, co mogłoby prowadzić do nadmiernego skomplikowania i zużycia zasobów bez realnych korzyści dla projektu. Wbudowany moduł wifi nie zostałby nigdy wykorzystany, natomiast moduł bluetooth który można by użyć w celu ewentualnego rozwinięcia projektu jest też dostępny w formie osobnego modułu dla Arduino Leonardo.

### 3.1.1. Moduł inercyjny

Do przechwytywania informacji w osiach XYZ zastosowane zostały moduły nawigacji inercyjnej. Na rynku dostępne są moduły wykorzystujące magnetometr, żyroskop oraz akcelerometr. Urządzenia te działając pojedynczo są podatne na błędy.

- magnetometr, wykorzystuje pole magnetyczne ziemi pomiar może być zakłócony przez różnego rodzaju magnesy.
- żyroskop, pozwala na dokładne wykrywanie położenia urządzenia. Jego działanie jest podatne na akumulację błędów w dłuższym okresie. Po pewnym czasie prowadzi to do nieakceptowalnych rezultatów.
- akcelerometr, podaje on dokładne pomiary pod warunkiem że jedyną siłą która na niego działa jest przyspieszenie ziemskie. Obracając urządzenie pomiary zaczynają oscylować, w praktyce oznacza to że w danych pojawia się dużo szumu.

22 | Kontroler urządzenia

Wybrany został moduł MPU6050 jest to moduł o 6 stopniach swobody. O wyborze modułu przeważyły biblioteki dostępne dla tego modelu. Pozwalają one na wykorzystanie wbudowanego procesora DMP (z angielskiego digital motion processor). W praktyce oznacza to że dane z akcelerometru i żyroskopu są łączone aby zniwelować swoje wady.
Warto również zwrócić uwagę na problem z odczytywaniem wartości z modułu MPU6050. Po dokładniejszej analizie stwierdzono, że w czasie pomiędzy odczytami wynoszącym od 19 ms do 49 ms, moduł nie zwraca żadnych danych. Początkowo przypuszczano, że problem leży w wadliwej lub uszkodzonej płytce/przewodach, jednakże nawet po zakupie nowego podzespołu problem nadal występował. Pod uwagę brana była możliwość zbyt dużego obciążenia Arduino ale to rówież okazało się nie być przyczyną. Jedyna informacja, która mogłaby wyjaśnić to zjawisko, została odnaleziona na forach internetowych. W tych źródłach podejrzewa się, że podczas odczytu z bufora, w wyżej wspomnianych interwałach czasowych, DMP z modułu MPU6050 blokuje wewnętrzny bufor w celu przeprowadzenia aktualizacji. Aby dokładnie określić momenty, w których moduł przestawał odpowiadać, zastosowano metodę ciągłego odczytywania wartości z MPU i wypisywania ich na port szeregowy (Serial Port). W każdej iteracji pętli dodawano także krótkie opóźnienie (delay) o 1 ms.

### 3.1.2. Inne

Ta podsekcja zawiera informacje o pozostałych komponentach które nie odgrywają tak ważnej roli w działaniu urządzenia niemniej jednak warto o nich wspomnieć.

- W celu przełączania trybów pracy urządzenia zastosowanio mikroswitche.
- W urządzaniu w roli wizualnej informacji zwrotnej zastosowano diody RGB lduino SE010. Każdy kolor został przypisany do odpowiedniej osi XYZ, i zapalany jest z odpowiednią intensywnością w zależności od wychylenia.

# Rozdział 4

# Instrukcja obsługi

Do złożenia urządzenia potrzebny będzie śrubokręt philips o średnicy nie większej niż 3 mm. Jest to konieczne ponieważ podczas montażu należy przewlec śrubokręt przez otwory o wspomnianej średnicy. Zaleca się aby śrubokręt był namagnesowany, ułatwia to umieszczenie nakrętek w odpowiednich slotach.
Potrzebne części można podzielić na elementy które należy wydrukować:
1. model sprężyny Y wersja A,
2. model sprężyny XY,
3. model gałki urządzenia,
4. model wierzchniej płytki,
5. model separatora,
6. model podstawy.

Oraz elementy które należy kupić:

1. 7 śrub M3x13,
2. 5 śrub M3x30,
3. 4 nakrętki M3,
4. 2 przyciski microswitch,
5. sensor MPU6050,
6. Arduino Pro Micro,
7. moduł diody RGB lduino SE010,
8. przewody do połączenia układu.

24 | Instrukcja obsługi

## 4.1. Składanie fizycznej części urządzenia

| Moduły TechDraw i ExplodedAssembly nie zostały zoptymalizowane do współpra-
cy ze sobą, co sprawia, że niemożliwe jest bezpośrednie generowanie szczegółowych instrukcji montażu w formie pliku PDF. Niemniej jednak, w ramach projektu udało się wykonać animację typu exploded assembly, prezentującą dynamiczny proces składania całego modelu. Animację można odtworzyć bezpośrednio w programie FreeCAD.

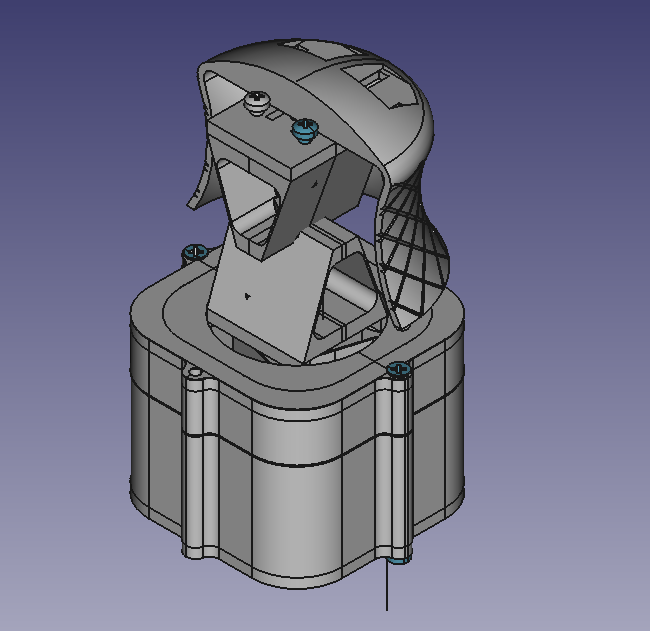
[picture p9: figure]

Rys. 4.1. Zrzut ekranu przedstawiający ułożenie sprężyn wewnątrz urządzenia FreeCAD.

Składanie fizycznej części urządzenia | 25


Rys. 4.2. Zrzut ekranu przedstawiający w pełni rozłożone urządzenie w programie FreeCAD.

1. W kroku pierwszym należy wstawić nakrętki M3 we wskazane sloty na rysunku 4.3.
2. Następnie używając otworu wskazanego na rysunku 4.4 przykręcić śrubę M3x10, tak aby połączyć ze sobą dwie sprężyny Y.

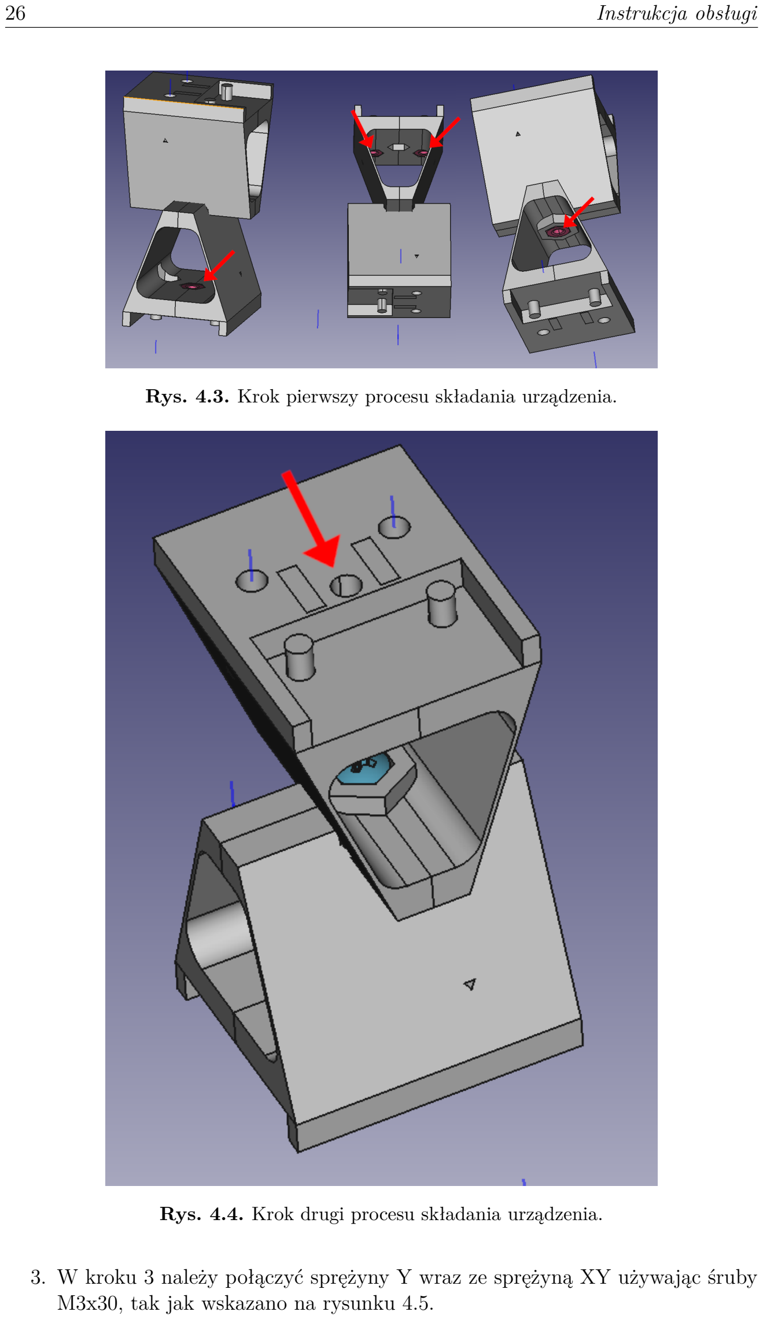
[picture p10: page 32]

26 | Instrukcja obsługi

Rys. 4.3. Krok pierwszy procesu składania urządzenia.

Rys. 4.4. Krok drugi procesu składania urządzenia.

3. W kroku 3 należy połączyć sprężyny Y wraz ze sprężyną XY używając śruby M3x30, tak jak wskazano na rysunku 4.5.

Składanie fizycznej części urządzenia | 27

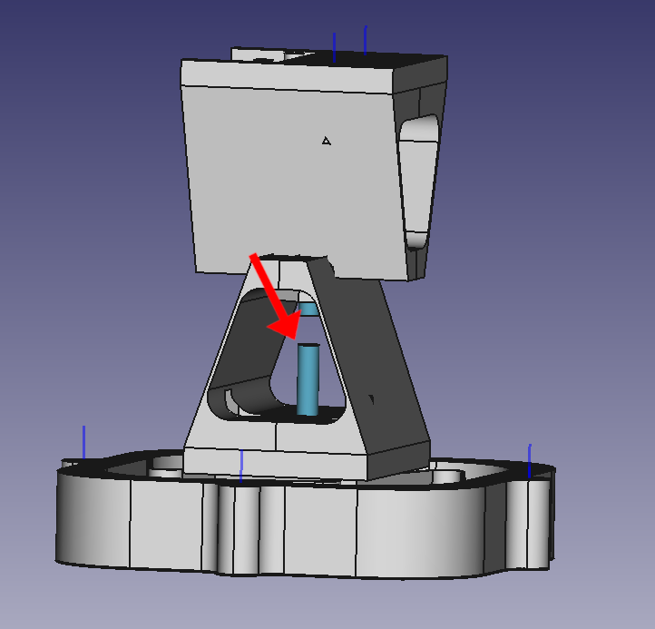
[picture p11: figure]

Rys. 4.5. Krok trzeci procesu składania urządzenia.

4. Następnie należy od spodu urządzenia nałożyć model dystansu obudowy, a na wierzchu nałożyć model górnej płytki. Elemenyt należy połączyć ze sobą za pomocą czterech śrub M3x30, w miejscach wskazanych na 4.6. Oraz ułożyć moduł MPU6050 w pasującym slocie.

28 | Instrukcja obsługi

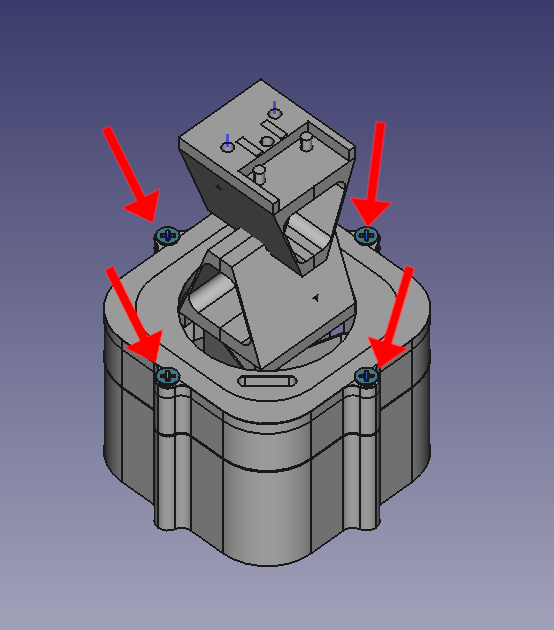
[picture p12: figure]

Rys. 4.6. Krok czwarty procesu składania urządzenia.

5. Przed nałożeniem modelu gałki należy przewlec przewody przez otwór wskazany przez strzałkę z numerem 1 na rysunku 4.7. Przewody należy podłączyć do MPU6050 i do microswitchy które następnie należy zamocować w slotach wskazanych przez strzałki z numerem 2. Następnie należy użyć śrub M3x10 do zamocowania gałki urządzenia do sprężyn w miejscach wskazanych przez strzałki oznaczone numerem 3.

Składanie fizycznej części urządzenia | 29

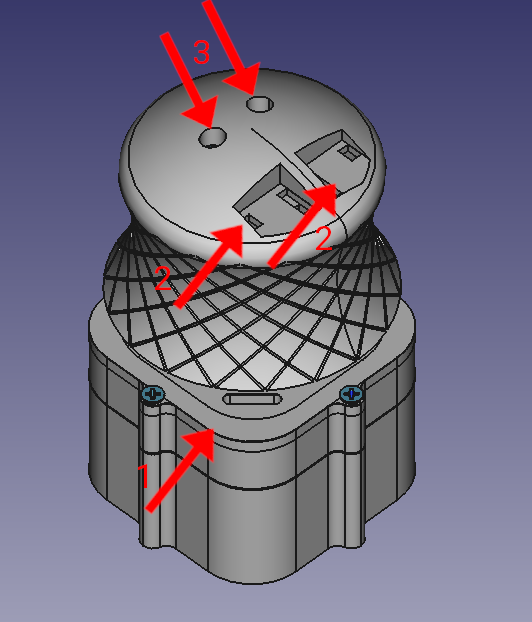
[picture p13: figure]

Rys. 4.7. Krok piąty procesu składania urządzenia.

6. W ostatnim kroku należy podłączyć przewody microswtchy, MPU6050 oraz modułu diody do Arduino i zamocować podstawę urządzenia za pomocą śrub M3x10 w miejscach wskazanych na rysunku 4.8.

30 | Instrukcja obsługi

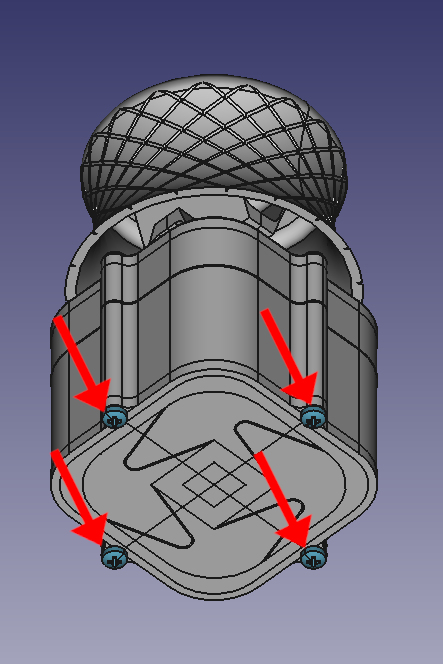
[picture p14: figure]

Rys. 4.8. Krok szósty procesu składania urządzenia.

Rys. 4.9 przedstawia schemat połączenia wszystkich komponentów elektronicznych. Moduł diody należy podłączyć pod piny analogowe A1, A2, A3. Układ wykorzystuje tylko piny SDA, SCL modułu MPU6050 które należy podłączyć kolejno do pinów 2 oraz 3. Microswitche należy podłączyć do pinów 7 oraz 8.

Wymagania software | 31

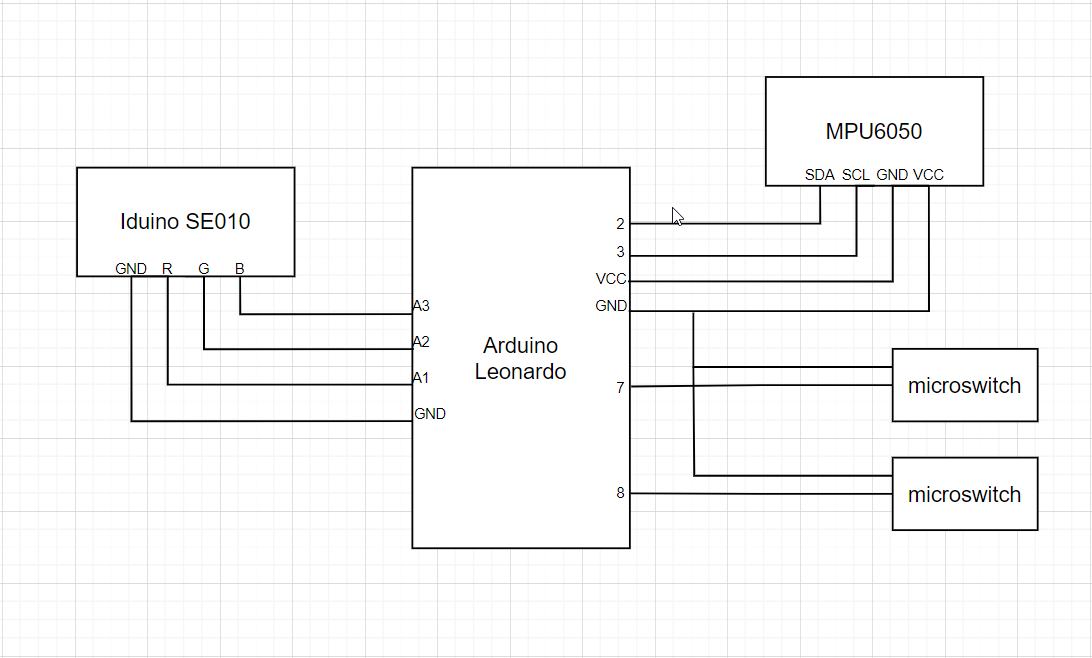
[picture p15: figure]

Rys. 4.9. Schemat podłączenia urządzenia.

## 4.2. Wymagania software

Należy pobrać oraz zainstalować Spacenavd ze strony projektu. Aby sterownik działał poprawnie trzeba mu podać ID urządzenia. W systemie Linux można zastosować poniższe polecenie aby utworzyć konfiguracje minimalną. Spacenavd [14] jest w stanie obsłużyć wiele urządzeń, więc możliwe jest wpisanie więcej niż jednego ID.

1 | sudo echo " d e vi c e−i d = $ ( l s u s b | g rep Arduino | cu t −d ’ ’ − f 6 ) " > / e t c / spn av rc

2

| Listing 4.1. Minimalna konfiguracja spacenavrc.
| Listing 4.1 pobiera informacje o wszystkich podłączonych urządzeniach USB wy- korzystując komendę lsusb. Przeszukuje je za pomocą polecenia grep a następnie wykorzystując polecenie cut wyciąga identyfikator urządzenia i zapisuje go do od- powiedniego folderu tak aby być w stanie współpracować z Spacenavd.

# Rozdział 5

# Wnioski

## 5.1. Mikrokontrolery

Z perspektywy czasu, wybór mikrokontrolerów Arduino do projektu, mimo swojej przyjazności dla użytkownika, nie był najlepszym rozwiązaniem. Mikrokontrolery Arduino są wprawdzie bardzo łatwe w użyciu i posiadają wiele gotowych bibliotek i narzędzi, ale ich możliwości są ograniczone w porównaniu do bardziej zaawansowanych mikrokontrolerów, takich jak STM32 i ESP32. Dodatkowo, warto zauważyć, że mikrokontrolery takie jak STM32 i ESP32 cenowo niewiele się różnią od mikrokontrolerów Arduino, a jednak posiadają funkcjonalności, które są krytycznie ważne dla rozwoju projektu. Na przykład, mikrokontroler STM32 pozwala na wykorzystanie debugera sprzętowego (ST-Link 2), który pozwala na bezpośrednie debugowanie kodu na poziomie sprzętu, który jest niezbędny w celu odnalezienia błędów. Dla porównania oficjalna dokumentacja Arduino zaleca debugowanie za pomocą interfejsu szeregowego (Serial). Natomiast w przypadku mikrokontrolera ESP32 poza sprzętowym debugowaniem, możliwe jest testowanie jednostkowe bezpośrednio na płytce[7], dzięki czemu testy jednostkowe są po prostu lepsze. Podsumowując hobbistyczna natura tej platformy ułatwiła pracę we wczesnym stadium projektu, ale w późniejszych stadiach opóźniła postęp.

### 5.1.1. MPU6050

W module żyroskopu i akcelerometru obie funkcjonalności działają na zasadzie komplementarnej. Żyroskop jest w stanie dość precyzyjnie wychwytywać zmiany swojego położenia, jednakże zbiera on ze sobą błąd który kumuluje się w miare popierania kolejnych próbek z modułu. Problem ten niweluje zastosowanie odczytu z akcelerometru i naniesienia poprawek. Stąd też wynika 6 stopni swobody urządzenia. W początkowej fazie projektowania błędnie założono że każdy stopień swobody odpowiadałby odpowiednio za osie X, Y, Z, rX, rY, rZ.

## 5.2. Modelowanie

Z powodu braku doświadczenia, dokonano niewłaściwego wyboru struktury projektu. W miarę tworzenia kolejnych modeli, zauważono, że praca stawała się coraz

Dalszy rozwój | 33

trudniejsza. W efekcie, napotkano trudności związane z wydajnością programu FreeCad, które wynikły z wcześniejszych decyzji projektowych. Na początku postanowiono trzymać wszystkie modele w jednym pliku. Jednak z biegiem czasu praktyka ta utrudniła pracę nad projektem. Okazało się, że prawidłowym podejściem byłoby tworzenie osobnego pliku dla każdego modelu. Pozwoliłoby to na lepszą organizację projektu, łatwiejsze zarządzanie i modyfikację poszczególnych modeli. Trzymając wszystko w jednym pliku, utracono przejrzystość i elastyczność, co przyczyniło się do trudności w pracy nad projektem.
Wykorzystanie techniki radełkowania oraz ergonomiczny kształt urządzenia zdecydowanie zwiększyły komfort w porównaniu do pierwszej iteracji gdzie zastosowano zwykły cylinder. Jednakże dłuższe użytkowanie urządzenia sprawia dyskomfort w palcach u dłoni. Jest to spowodowane tym że plastik PLA jest po prostu zbyt twardy. W kolejnej iteracji urządzenia należałoby pokryć czymś gałkę urządzenia lub zastosować inny materiał. Przykładem innego materiału mógłby być plastik TPU który jest znacznie bardziej elastyczny w porównaniu do PLA.

## 5.3. Dalszy rozwój

Potencjalne pomysły aby rozbudować projekt:

- Klawiatura makr, po zbudowaniu prototypu i przetestowaniu go w docelowych aplikacjach stwierdzono brak możliwości szybkiego korzystania ze skrótów klawiszowych. Rozwiązaniem byłaby klawiatura zawierająca programowalne makra. Najodpowiedniejsze byłoby rozwiązanie modularne. Pozwoliłoby to użytkownikowi na zapoznanie się z podstawową wersją urządzenia, a w przyszłości dałoby możliwość jego rozbudowy. W przypadku komercjalizacji projektu oznaczałoby to, że potencjalny klient inwestując w bazową wersję mógłby potencjalnie stać się powracającym klientem i inwestowałby dalej w ekosystem urządzenia.
- Formowanie wtryskowe, aktualnie modele są przygotowane pod wydruk 3D dla materiały PLA. Pozwala to tylko na produkcję urządzenia na małą skale. Zastosowanie form wtryskowych pozwoliłoby zmniejszyć czas trwania produkcji oraz zwiększyć jakość tworzonych części. Oznaczałoby to potrzebę zmodyfikowania bieżących modeli oraz przeprowadzenie nowych symulacji ponieważ formy wtryskowe wykorzystują plastik ABS.
- Czujnik pojemnościowy, aby korzystać z urządzenia trzeba przytrzymywać przycisk odpowiedzialny za nadawanie. Można by zwiększyć komfort użytkowania poprzez zastosowanie czujnika pojemnościowego w gałce urządzenia. Oznaczałoby to rozpoczęcie nadawania przez urządzenie natychmiast po wykryciu dotyku.
- Połączanie trybów XYZ oraz rXrYrZ, czujnik MPU6050 nie pozwala na wykrywania ruchu w obu trybach jednocześnie. Potrzebny byłby inny sensor aby było to możliwe potencjalnym rozwiązaniem mogłyby się okazać magnesy oraz czujniki Halla.

34 | Wnioski
- Dedykowana płytka PCB, stworzenie dedykowanej płytki pozwoliłoby na stworzenie linii produkcyjnej. Po projekcie płytki następnie należałoby zająć się zestawem testów jakościowych:

– X-ray, testy z wykorzystaniem X-ray wykonywane są aby sprawdzić poprawność lutów oraz mocowania komponentów na płytce PCB. Testy za pomocą X-ray są szczególnie ważne w przypadku stosowania cyny bezołowiowej ponieważ która jest znacznie bardziej skłonna do mikropęknięć. – ICT, (In-Circuit-Test) jest to metoda sprawdzania poprawności działania komponentów nałożonych już na płytkę. Umożliwia wykrycie różnych rodzajów błędów, takich jak zwarcia, przerwy, błędy w rezystancji czy pojemności. W zależności od planowanego wolumenu zastosować można tester typu flying probe, lub tester z dedykowaną fiksturą.
– FIT, (Fault Injection Test) tego typu testy polegają na celowym uszkadzaniu płytek PCB i ponownym przeprowadzeniu testów.

Testy typu HBT oraz BIC zostały pominięte w tym zestawieniu ponieważ urządzenie nie było projektowanie z myślą o pracy w temperaturach ekstremalnych.

- Rozwój projektu od strony software, w sekcji omawiającej testowanie oprogramowania wspomniano o klasach które nie zostały wykorzystane. Napisano klasy które pozwalają ukryć niepotrzebny kod protowątków. Listing 5.1 znacznie upraszcza korzystanie z protowątków. Klasa Protothread powstała z myślą o tym aby być klasą bazową. Klasy pochodne miałby nadpisywać metodę wirtualną operation(), oraz ewentualnie dodawać własne zmienne które byłby potrzebne w protowątku.
1 | #i f n d e f PROTOTHREAD
2 | #d e f i n e PROTOTHREAD

3
4 | #i n cl u d e <pt . h>
5 | #i f n d e f ARDUINO
6 | #i n cl u d e <chrono>

7
8 | c l a s s myTimer
9 | {
10 | p u bli c :
11 | myTimer ( ) { s t a r t = s t d : : chrono : : s t e a d y_ cl o c k : : now ( ) ; }
12 | un si gned l o n g o p e r a t o r ( ) ( )
13 | {
14 | r e t u r n s t d : : chrono : : du r a ti on_c a s t<s t d : : chrono : :
| m i l l i s e c o n d s >( s t d : : chrono : : s t e a d y_ cl o c k : : now ( ) − s t a r t ) .
| count ( ) ;
15 | ;
16 | }

17
18 | p r i v a t e :
19 | s t d : : chrono : : time_point<s t d : : chrono : : s te ady_cl ock> s t a r t
| ;
20 | } ;

Dalszy rozwój | 35

21
22 | myTimer m i l l i s ;
23 | #e n d i f

24
25 | c l a s s P r o t o th re ad
26 | {
27 | un si gned l o n g threadTimer { 1 0 };
28 | un si gned l o n g tim e r { 0 };
29 | pt th re ad ;

30
31 | p u bli c :
32 | P r o t o th re ad ( ) {}
33 | P r o t o th re ad ( c o n s t P r o t o th re ad &p )
34 | {
35 | threadTimer = p . threadTimer ;
36 | th re ad = p . th re ad ;
37 | } ;
38 | v oid setThreadTimer ( un si gned l o n g newTimer )
39 | {
40 | threadTimer = newTimer ;
41 | }
42 | v oid i n i t ( )
43 | {
44 | PT_INIT(& th re ad ) ;
45 | }
46 | v oid run ( )
47 | {
48 | PT_BEGIN(& th re ad ) ;
49 | w hil e ( 1 )
50 | {
51 | tim e r = m i l l i s ( ) ;
52 | PT_WAIT_UNTIL(& thread , m i l l i s ( ) − tim e r >
| threadTimer ) ;
53 | o p e r a ti o n ( ) ;
54 | }
55 | PT_END(& th re ad ) ;
56 | }
57 | v i r t u a l v oid o p e r a ti o n ( ) = 0 ;
58 | } ;

59
60 | #e n d i f // PROTOTHREAD
| Listing 5.1. Przykładowe testy jednostkowe.
| Ponieważ protowątki wykorzystują wbudowany w bibliotekę Arduino timer
| millis(). Została napisana klasa myTimer którą widać na listingu 5.1. Jest
| ona includowana tylko wtedy kiedy kompilator wykryje brak klasy Arduino.
| Podczas tworzenia instancji klasy myTimer mierzony jest czas. Dzięki prze-
| ładowaniu operatora () i stworzeniu obiektu o nazwie millis możliwe jest
| korzystanie z klasy jako funktora dzięki czemu klasa Protothread zachowuje
| się tak samo zarówno na Arduino jak i na komputerze.

36 | Wnioski
1 | #i f n d e f JOYSTICK_PROTOTHREAD
2 | #d e f i n e JOYSTICK_PROTOTHREAD

3
4 #i n cl u d e <J o y s ti c kEm ul a t o r . h>

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

Dalszy rozwój | 37
48 | }
49 | } ;

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

66
67 | #e n d i f // !JOYSTICK_PROTOTHREAD
| Listing 5.2. Przykładowe testy jednostkowe.
| Listing 5.2 przedstawia klasę pochodną JoystickProtothread od omówionej
| w listingu 5.1 klasy Protothread. Klasa pochodna ma prywatne zmienne ypr
| jest to tablica która zawiera kolejno yaw, pitch, roll. Klasa zwiera również
| wskaźnik do abstrakcyjnej klasy JoystickEmulator dzięki czemu może obsłu-
| giwać omówione w projekcie adaptery. Klasa powstawała z myślą o wzorcach
| projektowych strategii oraz maszyny stanów. Idea była taka aby urządzenie
| w zależności od stanu w którym się znajduje podmieniałoby zachowanie za
| pomocą metody setStrategy(). Na implementację samej maszyny stanów
| zabrakło czasu.
1 | . . .
2 | TEST( P r o t o th re adTe s t s , RunFunctionInTheLoop )
3 | {
4 | s t r u c t P r o t o t h r e a dT e s t e r : P r o t o th re ad
5 | {
6 | i n t count { 0 };
7 | v oid o p e r a ti o n ( ) o v e r r i d e
8 | {
9 | count++;
10 | }
11 | } ;
12 | P r o t o t h r e a dT e s t e r uni tUnde rTes t ;
13 | un si gned l o n g i n t tim e r = m i l l i s ( ) ;
14 | w hil e ( m i l l i s ( ) − tim e r < 5 0 )
15 | {

38 | Wnioski
16 | uni tUnde rTes t . run ( ) ;
17 | }
18 | EXPECT_GT( uni tUnde rTes t . count , 1 ) ;
19 | }

20
21 | TEST( J o y s ti c kP r o t o t h r e a d T e s t s ,
| XYZS t r a te g yC allin g J o y s tic kAd ap te r )
22 | {
23 | c o n s t e x p r f l o a t EXPECTED{ 1 };
24 | JoystickMock j ;
25 | J o y s ti c kEm ul a t o r &&j o y s t i c k = J o y s ti c kLi b r a r yA d a p t e r ( j ) ;
26 | f l o a t ypr [ 3 ] ;
27 | ypr [ 0 ] = EXPECTED;
28 | ypr [ 1 ] = EXPECTED;
29 | ypr [ 2 ] = EXPECTED;
30 | J o y s ti c kP r o t o t h r e a d uni tUnde rTes t ( ypr , j o y s t i c k ) ;
31 | uni tUnde rTes t . s e t S t r a t e g y (new XYZ) ;
32 | EXPECT_CALL( j , se tXAxis (EXPECTED) ) . Times ( 1 ) ;
33 | EXPECT_CALL( j , se tYAxis (EXPECTED) ) . Times ( 1 ) ;
34 | EXPECT_CALL( j , s e tZA xi s (EXPECTED) ) . Times ( 1 ) ;
35 | uni tUnde rTes t . o p e r a ti o n ( ) ;
36 | }

37
38 | TEST( J o y s ti c kP r o t o t h r e a d T e s t s ,
| RXRYRZStrategyCallingJoystickAdapter )
39 | {
40 | c o n s t e x p r f l o a t EXPECTED{ 1 };
41 | JoystickMock j ;
42 | J o y s ti c kEm ul a t o r &&j o y s t i c k = J o y s ti c kLi b r a r yA d a p t e r ( j ) ;
43 | f l o a t ypr [ 3 ] ;
44 | ypr [ 0 ] = EXPECTED;
45 | ypr [ 1 ] = EXPECTED;
46 | ypr [ 2 ] = EXPECTED;
47 | J o y s ti c kP r o t o t h r e a d uni tUnde rTes t ( ypr , j o y s t i c k ) ;
48 | uni tUnde rTes t . s e t S t r a t e g y (new RXRYRZ) ;
49 | EXPECT_CALL( j , setRxAxis (EXPECTED) ) . Times ( 1 ) ;
50 | EXPECT_CALL( j , setRyAxis (EXPECTED) ) . Times ( 1 ) ;
51 | EXPECT_CALL( j , se tRzAxi s (EXPECTED) ) . Times ( 1 ) ;
52 | uni tUnde rTes t . o p e r a ti o n ( ) ;
53 | }
54 | . . .
| Listing 5.3. Przykładowe testy jednostkowe.
| Listing 5.3 zawiera testy napisane dla klasy Protothread oraz jej pochodnych.
| Test RunFunctionInTheLoop tworzy strukturę ProtothreadTester oraz nad-
| pisuje metodę operation() w której zlicza ilość wykonań pętli. Wymagane jest
| wykonanie więcej niż jednej pętli. Wymóg ten został postawiony ponieważ w
| zależności od szybkości procesora i dostępnych zasobów zmienna count z testu
| na test może mieć inne wartości ale gwarantowane jest że jeżeli wszystko działa
| poprawnie to wykona się więcej niż jeden raz. Z racji że ProtothreadTester
| tworzone jest tylko i wyłącznie na potrzeby testów zdecydowano się na struk-

Dalszy rozwój | 39

turę dzięki czemu upraszcza to dostęp do zmiennej count która w strukturze jest domyślnie publiczna.

Testy XYZStrategyCallingJoystickAdapter oraz RXRYRZStrategyCallingJoystickAdapter działają w sposób analogiczny do testów omówionych w listingu 2.9. Aby omówione w tej sekcji klasy działały poprawnie należy zaimplementować wzorzec maszyny stanów.

# Dodatek A

# Schematy urządzenia

Niniejszy dodatek zawiera schematy opracowanego urządzenia.

13,00

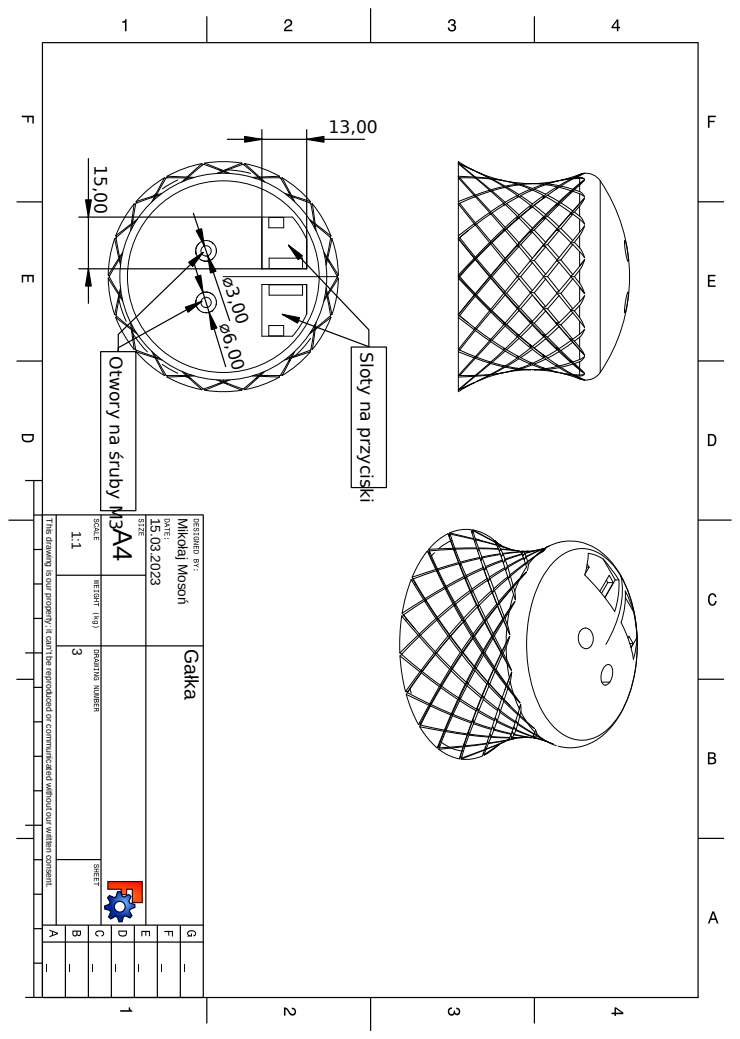
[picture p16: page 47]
Mikołaj Mosoń; Gałka

3 Otwory na śruby M3

1 Sloty na przyciski

This drawing is our property; it can't be reproduced or communicated without our written consent.

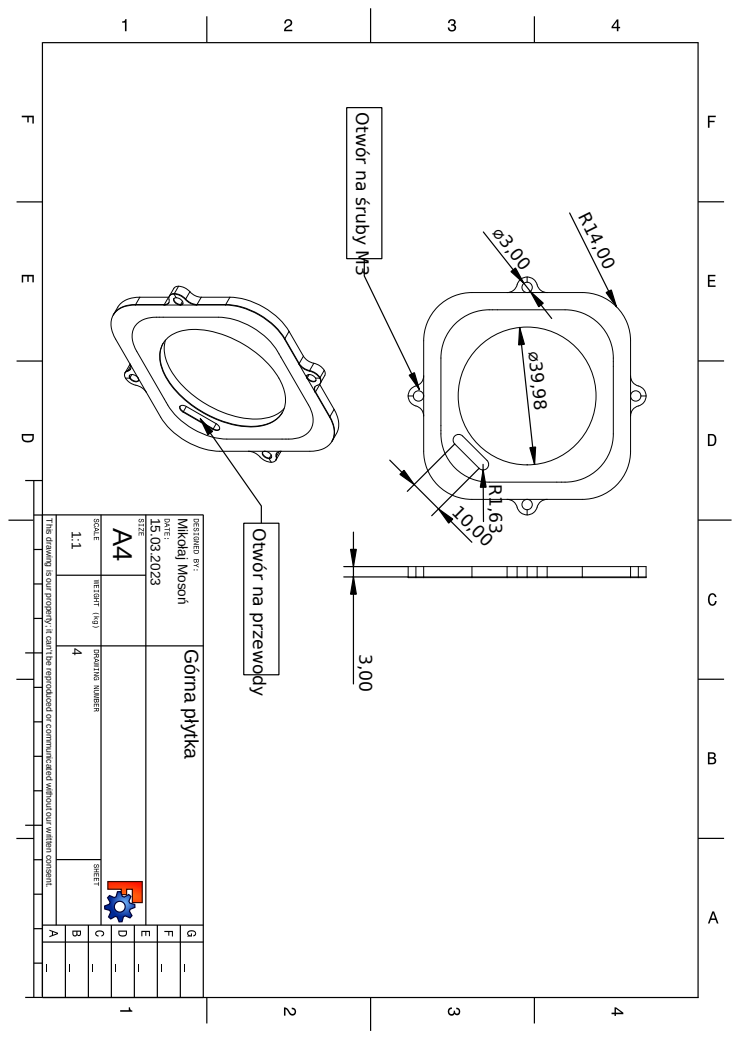
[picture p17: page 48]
Mikołaj Mosoń; Górna płytka

Otwór na śruby M3 3,00

This drawing is our property; it can't be reproduced or communicated without our written consent.

Otwór na przewody

56,00

60,00

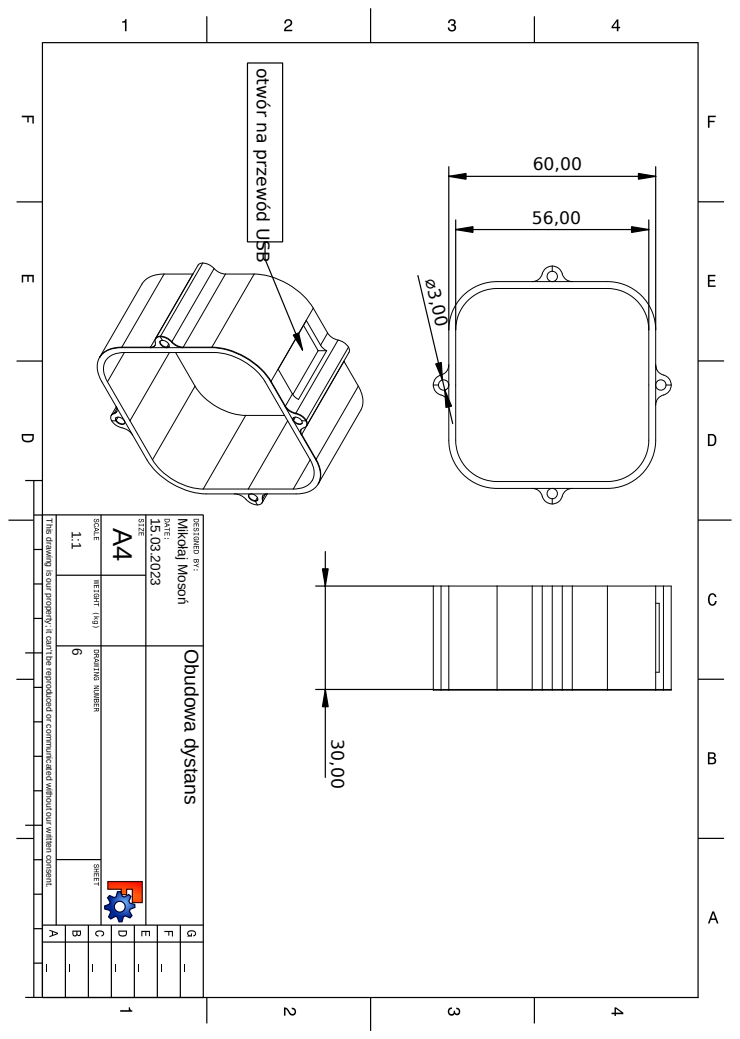
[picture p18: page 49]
Mikołaj Mosoń; Obudowa dystans

otwór na przewód USB

This drawing is our property; it can't be reproduced or communicated without our written consent.

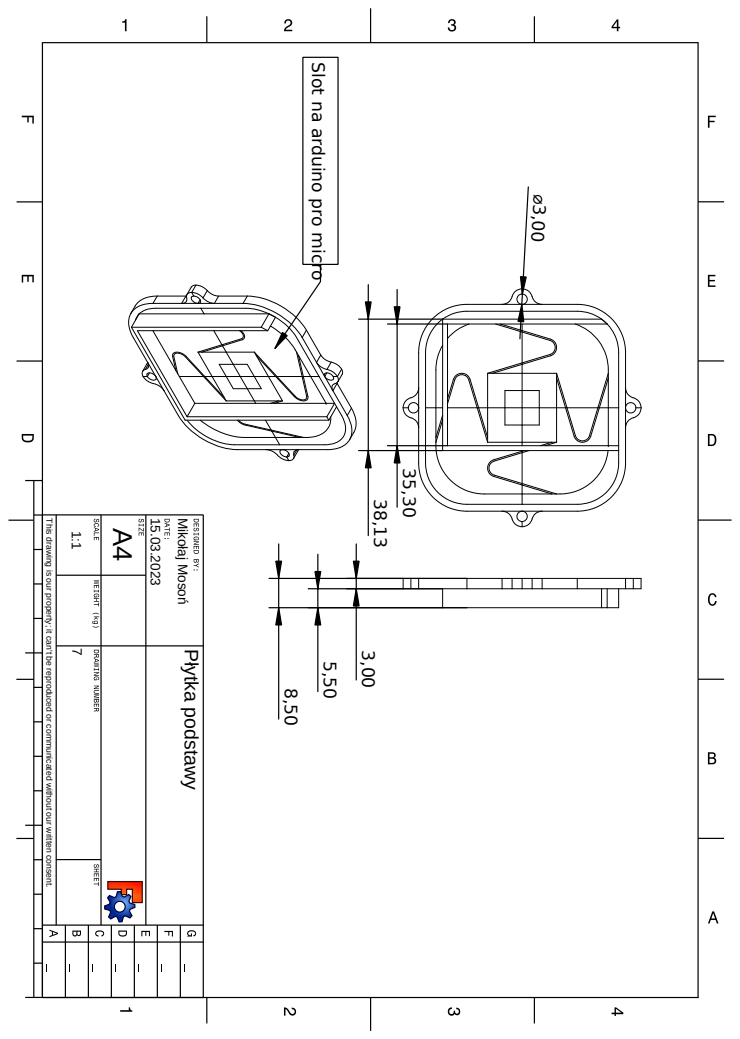
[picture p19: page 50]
Mikołaj Mosoń; Płytka podstawy

Slot na arduino pro micro

This drawing is our property; it can't be reproduced or communicated without our written consent.

20,00

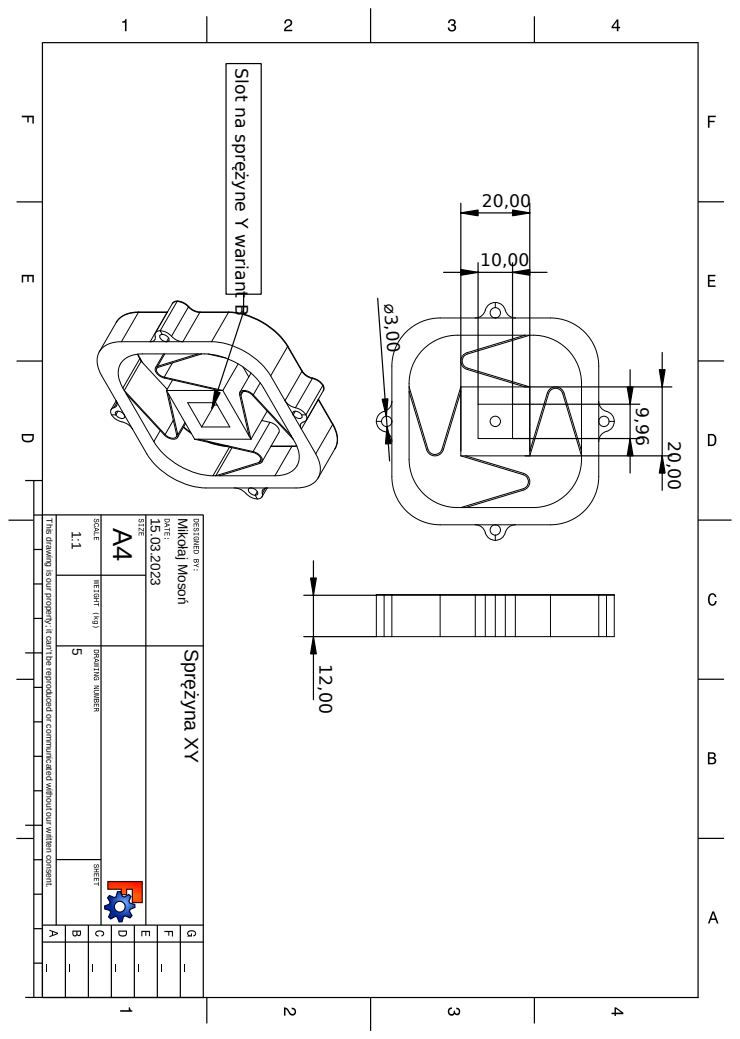
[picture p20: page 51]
Mikołaj Mosoń; Sprężyna XY

Slot na sprężyne Y wariant B

This drawing is our property; it can't be reproduced or communicated without our written consent.

30,00 | 7,50

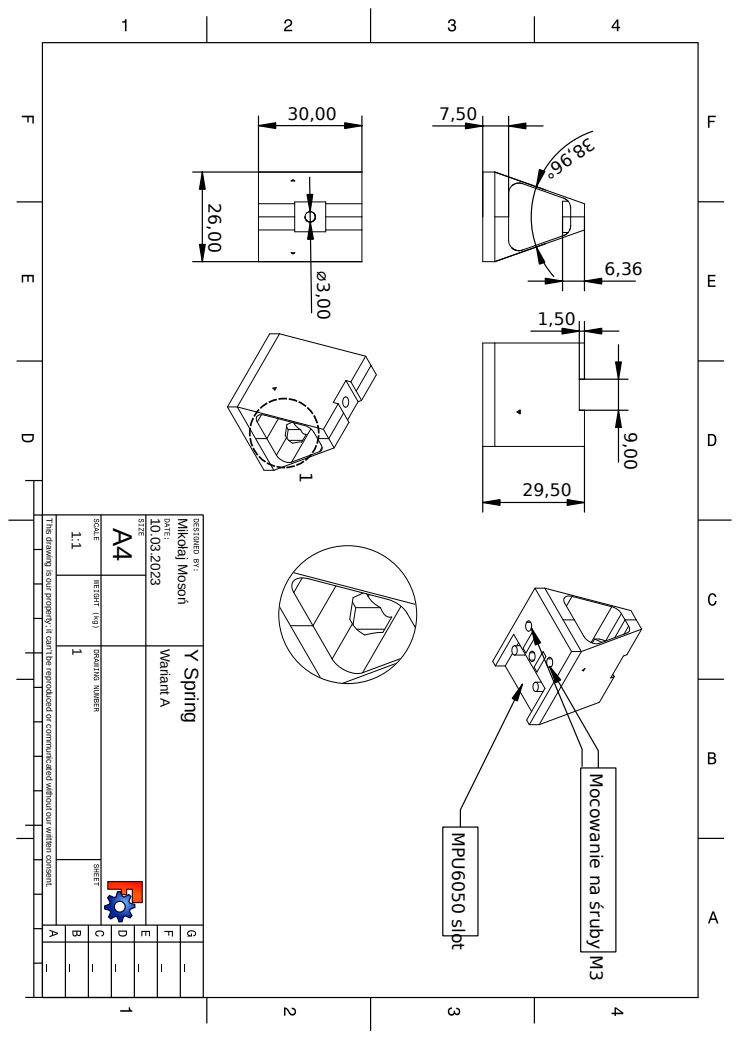
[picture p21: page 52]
Mikołaj Mosoń; Wariant A; Y Spring; MPU6050 slot

This drawing is our property; it can't be reproduced or communicated without our written consent.

Mocowanie na śruby M3

47

# Bibliografia

[1] Various athors. Trackball. https://en.wikipedia.org/wiki/Trackball, 2023.
[2] Various athors. Joystick. https://en.wikipedia.org/wiki/Joystick, 2023.
[3] 3DConnexion. 3DConnexion official website. https://3dconnexion.com/pl/product/spacemouse-compact/, 2023.
[4] Valve. Steam official website. https://store.steampowered.com/app/353370/Steam_Controller/, 2023.
[5] Arduino. Arduino Official Website. https://www.arduino.cc/en/software, 2023.
[6] Microsoft. Visual Studio Code Official Website. https://code.visualstudio.com/, 2023.
[7] PlatformIO. PlatformIO: An open-source ecosystem for IoT development. https://platformio.org/, 2023.
[8] FreeCAD. FreeCAD Official Website. https://www.freecadweb.org/, 2023.
[9] Create Education. Cura Software. https://www.createeducation.com/software/cura/, 2023.
[10] Tevoup. Tornado 3D Printer. https://tevoup.com/collections/tornado, 2023.
[11] Prusa3D. Prusament PLA. https: //www.prusa3d.com/en/product/prusament-pla-prusa-orange-1kg/, 2023.
[12] Prusa Polymers by Joseph Prusa. Karta Danych Technicznych Prusament PLA firmy Prusa Polymers, Luty 2022.
[13] Google. Google Test. https://github.com/google/googletest, 2023.
[14] jtsiomb. SpaceNavD. https://spacenav.sourceforge.net/index.html, 2023.
[15] Various contributors. Handbook of Compliant Mechanisms. A John Wiley Sons, Ltd., Publication, John Wiley Sons Ltd, The Atrium, Southern Gate, Chichester, West Sussex, PO19 8SQ, United Kingdom, 2013.

Bibliografia | 49
[16] Społeczność FreeCAD. Dokumetacja freecad. https://www.freecadweb.org/wiki/Main_Page, 2023.
[17] Elecia White. Making Embedded Systems: Design Patterns for Great Software. O’Reilly and Associates, California, USA, 2011.
[18] Richard Helm John Vlissides Erich Gamma, Ralph Johnson. Design Patterns: Elements of Reusable Object-Oriented Software. Addison-Wesley, USA, 2009.
[19] Tom Mason Dave Madison, Benjamin Van Ryseghem. Arduinoxinput. https://github.com/dmadison/ArduinoXInput, 2023.
[20] ThrowTheSwitch. Unity. https://github.com/ThrowTheSwitch/Unity/tree/master, 2023.
[21] Microchip. Atmel official website. https://start.atmel.com/, 2023.
[22] PJRC. Teensy official website. https://www.pjrc.com/teensy/, 2023.
[23] Arm Holdings. Arm official website. https://www.arm.com/products/silicon-ip-cpu, 2023.

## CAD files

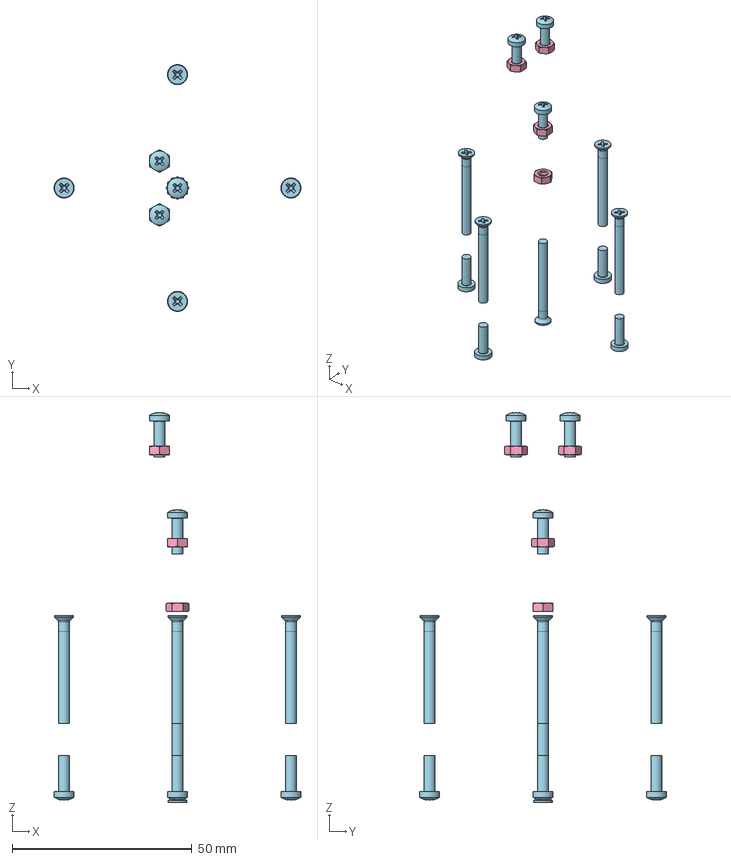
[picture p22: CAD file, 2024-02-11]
models/mouseAssembly.FCStd
68.6 x 68.6 x 108.3 mm
M3x30-Screw
M3x30-Screw309
M3x30-Screw310
M3x30-Screw311
M3x10-Screw
M3x10-Screw789
M3x10-Screw790
M3x10-Screw791
M3x10-Screw792
M3x10-Screw793
M3x30-Screw312
M3x10-Screw794
M3-Nut
M3-Nut238
M3-Nut239
M3-Nut240

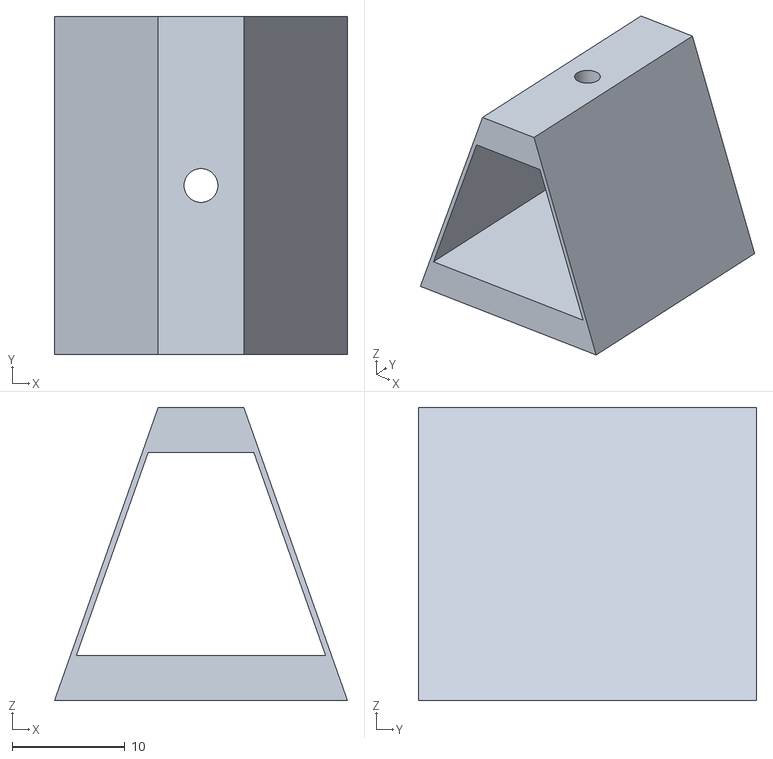
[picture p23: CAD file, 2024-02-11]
models/STL/mouse-Y spring simple.stl
26.0 x 30.0 x 26.0

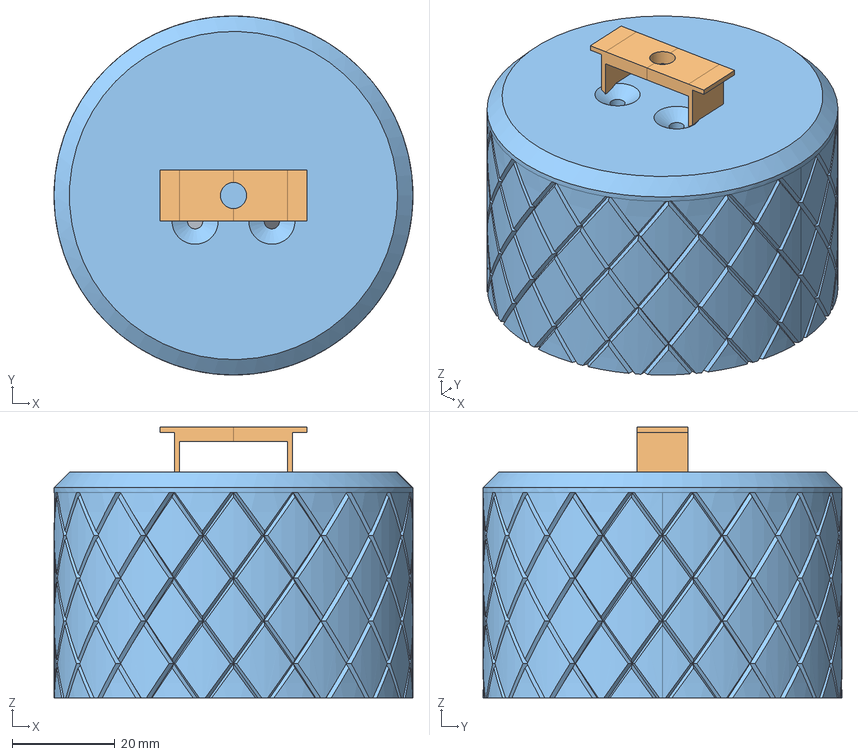
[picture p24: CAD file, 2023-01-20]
models/mouse.FCStd
70.0 x 70.0 x 52.8 mm
Y spring
X spring hole clip
Knob
encoder and gyro holder

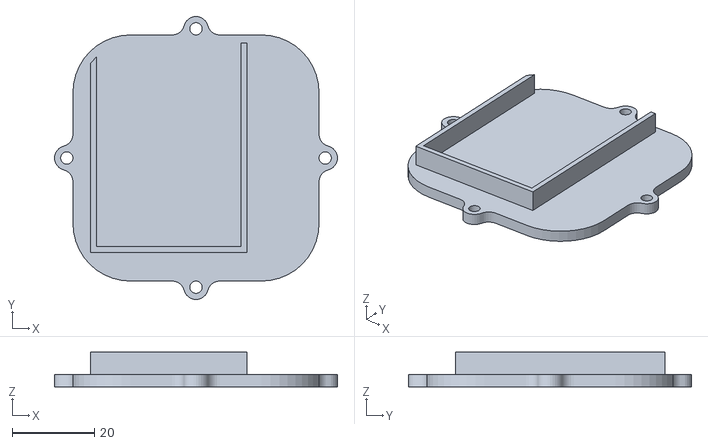
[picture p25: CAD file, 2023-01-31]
models/STL/mouse-breadboard plate.stl
69.0 x 69.0 x 8.50

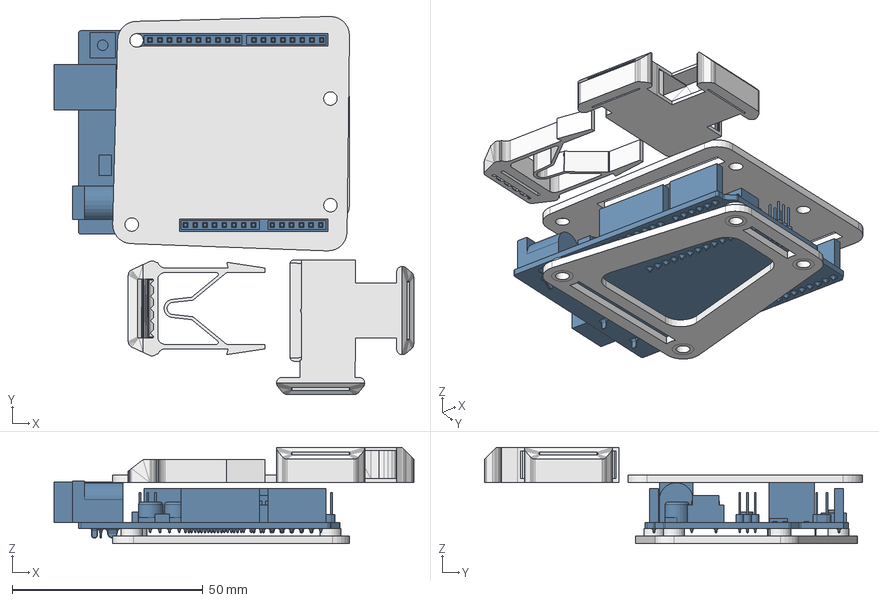
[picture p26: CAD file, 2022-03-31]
models/arduinoGlove.FCStd
94.2 x 99.1 x 25.2 mm
Arduino
Top
Bottom
buckleA
buckleB

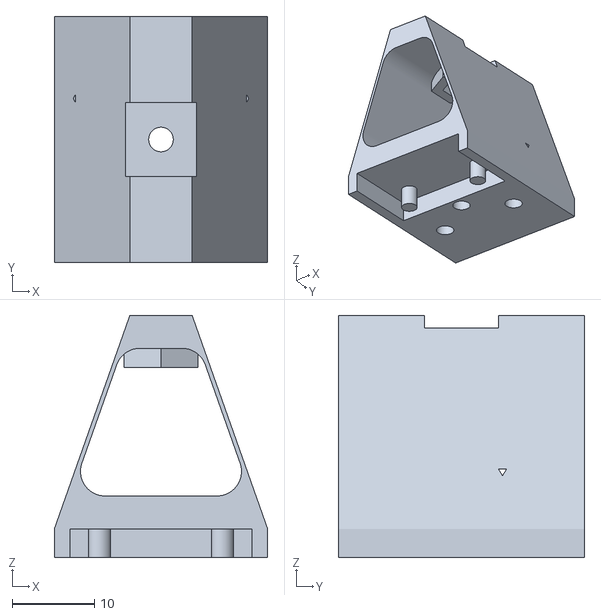
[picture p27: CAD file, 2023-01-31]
models/STL/mouseYspring.stl
26.0 x 30.0 x 29.5

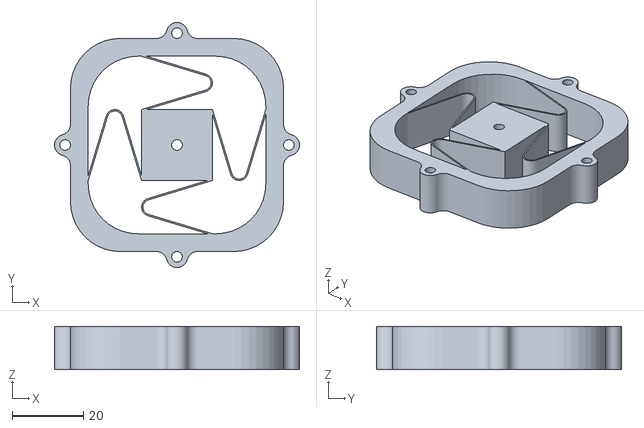
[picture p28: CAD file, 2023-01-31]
models/STL/mouseXYStage.stl
69.0 x 69.0 x 12.2

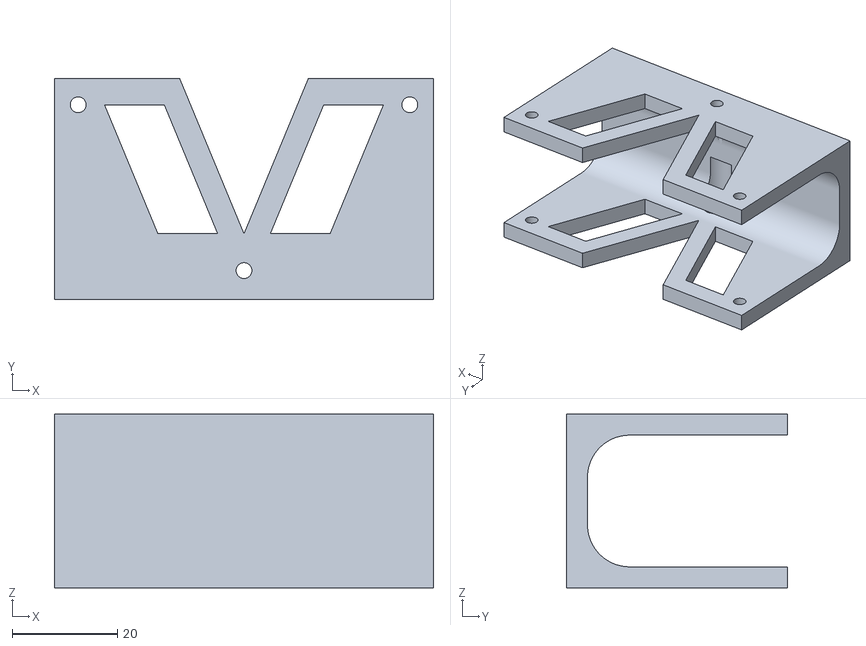
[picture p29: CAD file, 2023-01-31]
models/STL/mouse-clamp.stl
72.0 x 42.0 x 33.0

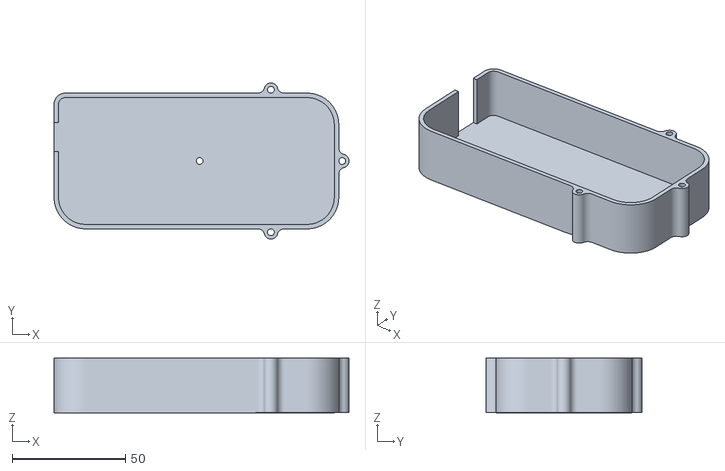
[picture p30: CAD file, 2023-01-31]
models/STL/mouse-case base.stl
130.4 x 69.0 x 24.2

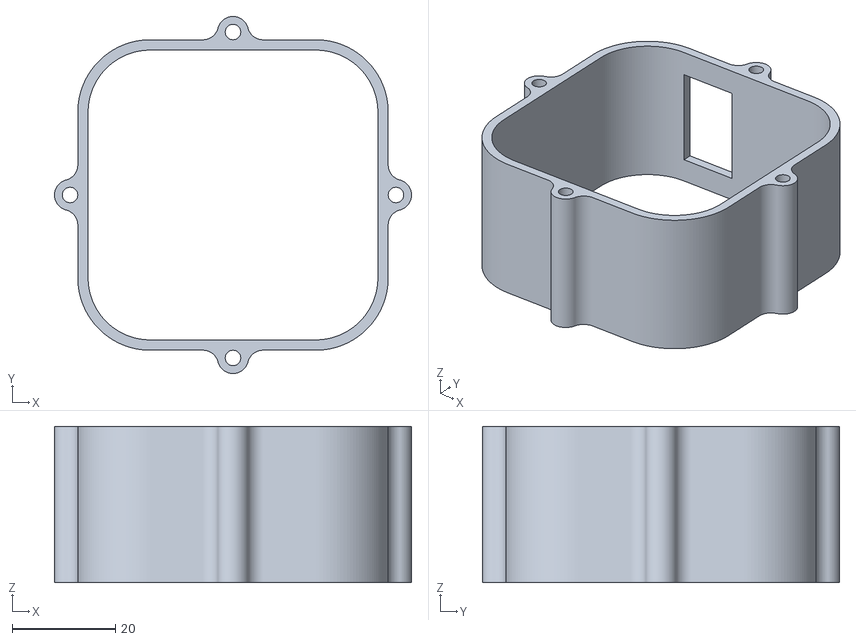
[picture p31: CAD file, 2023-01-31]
models/STL/mouse-spacer.stl
69.0 x 69.0 x 30.2

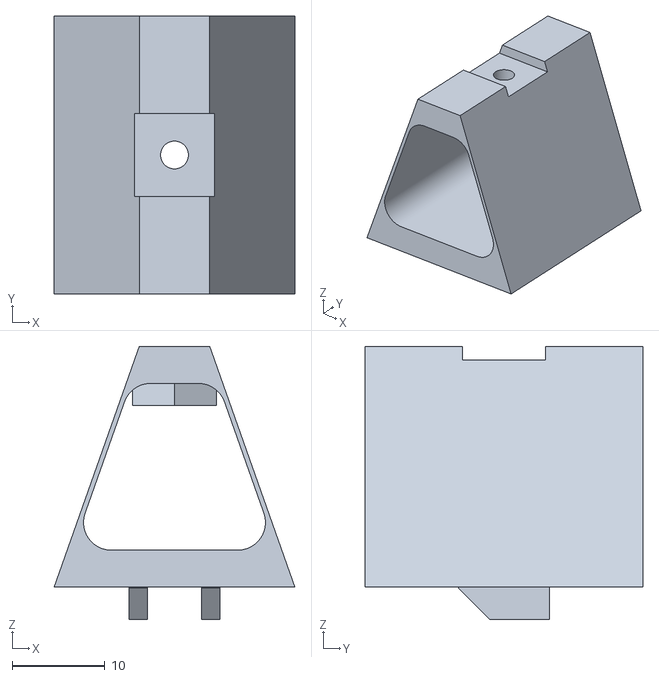
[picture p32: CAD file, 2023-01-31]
models/STL/mouse-Y bottom.stl
26.0 x 30.0 x 29.5

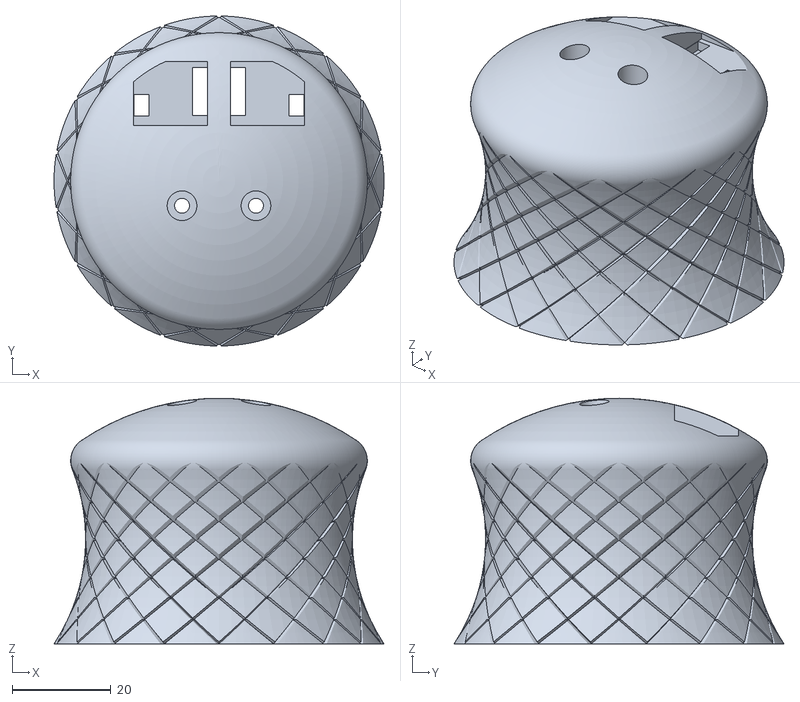
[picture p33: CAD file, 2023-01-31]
models/STL/mouse-knob2.stl
66.7 x 66.7 x 49.7

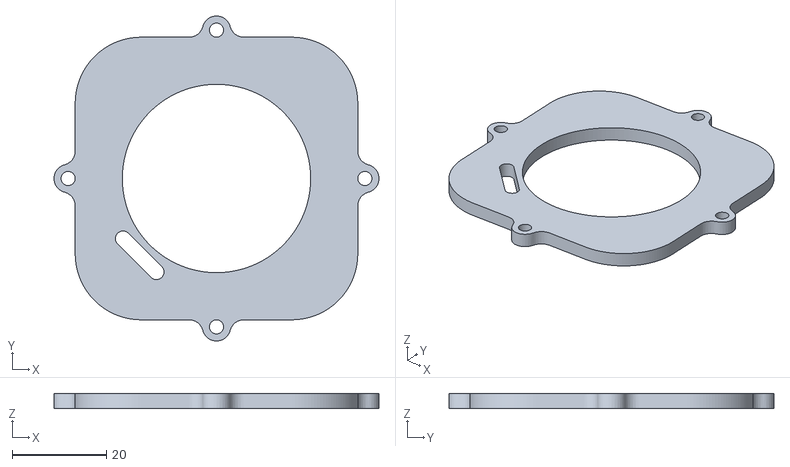
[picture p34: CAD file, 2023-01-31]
models/STL/mouse-XY plate.stl
69.0 x 69.0 x 3.20

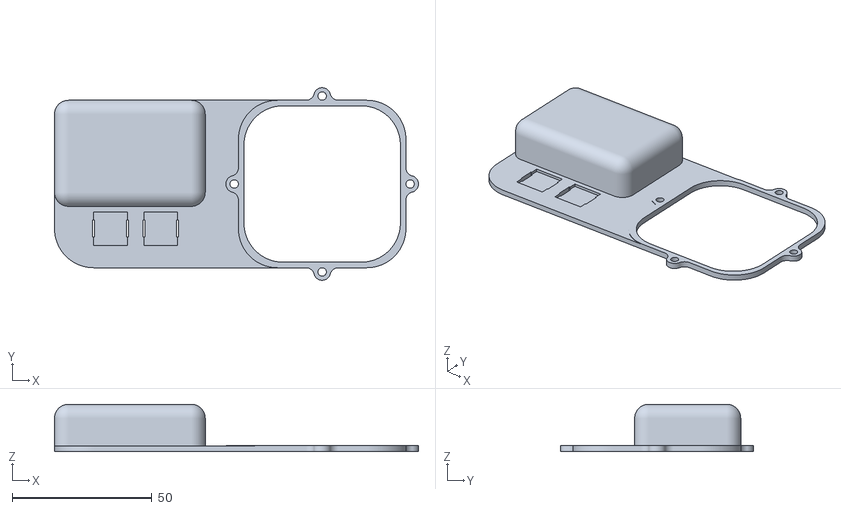
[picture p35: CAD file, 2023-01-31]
models/STL/mouse-case plate.stl
130.4 x 69.0 x 17.0

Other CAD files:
models/STL/mouse-spacerPocket057.stl
models/STL/mouseYspring2.stl
models/STL/encoderholder.stl
models/STL/mouse-Knob.stl
models/STL/arduinoGloveBottomPad.stl
models/STL/arduinoGloveSpacer.stl
models/STL/arduinoGloveTopPad.stl
models/STL/mouseOrthoPlanarSpring.stl
models/STL/mouseXspring.stl
models/STL/mouseXspringHoleClip.stl
models/STL/mouseXspringWithHole.stl
models/STL/mouseZspring.stl

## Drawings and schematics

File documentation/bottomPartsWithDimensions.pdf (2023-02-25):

⌀39,98

9,96

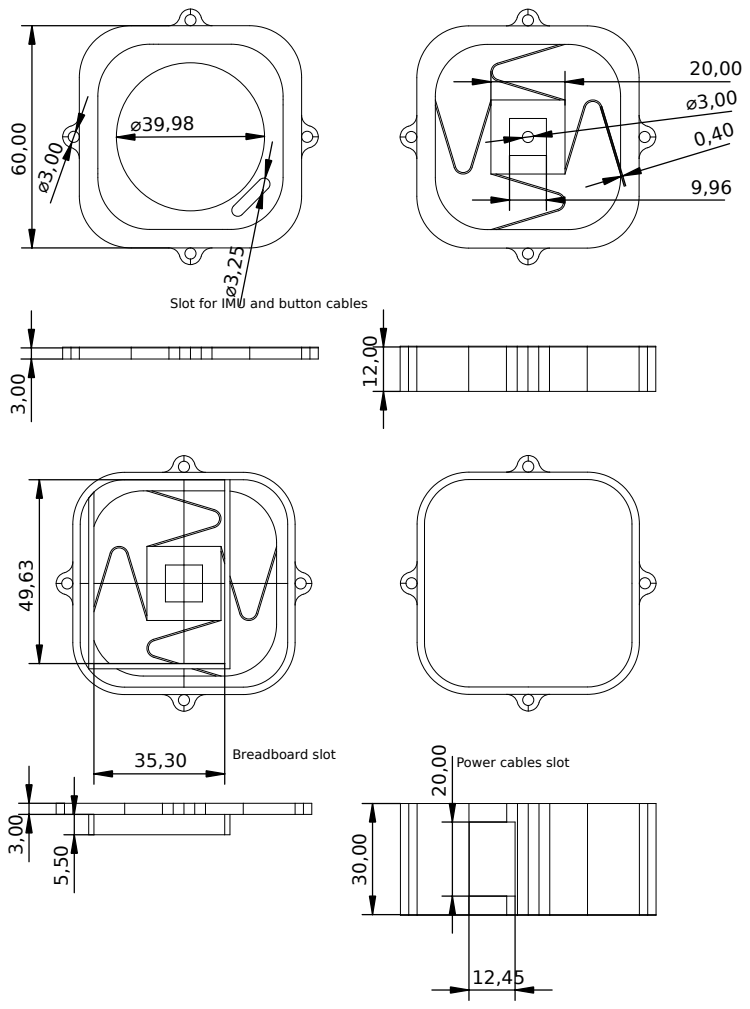
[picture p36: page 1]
Power cables slot; Breadboard slot

Slot for IMU and button cables

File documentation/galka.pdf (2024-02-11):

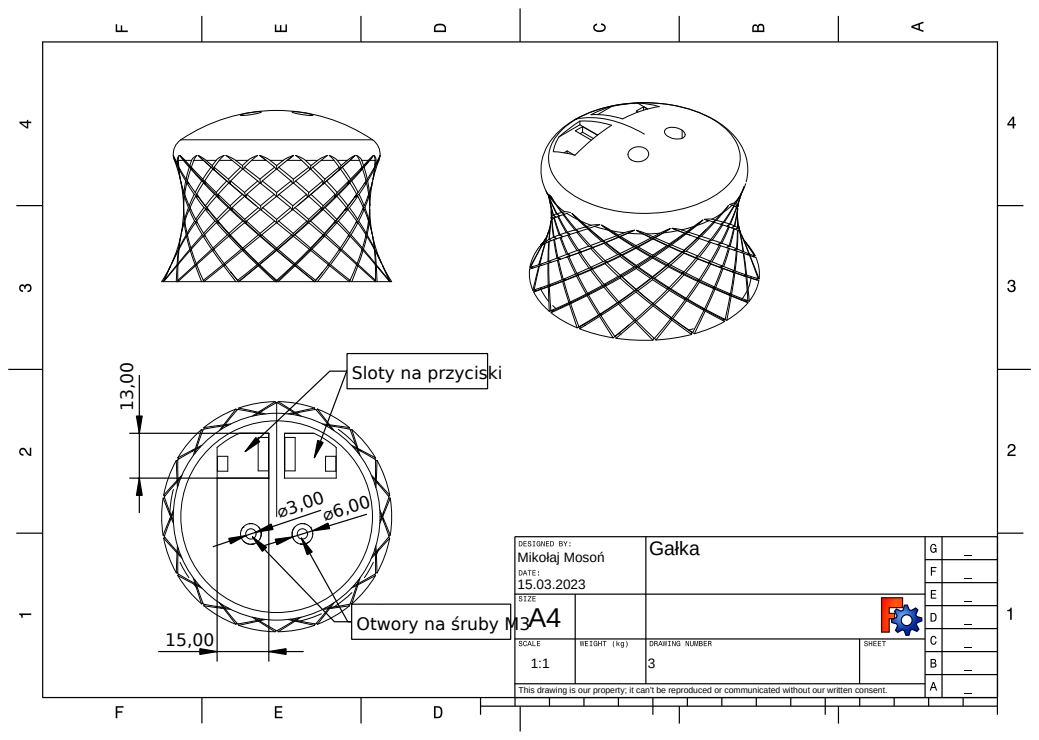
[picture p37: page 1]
Otwory na 3; śruby M3

Sloty na przyciski 1

Mikołaj Mosoń 15.03.2023 | Gałka

This drawing is our property; it can't be reproduced or communicated without our written consent.

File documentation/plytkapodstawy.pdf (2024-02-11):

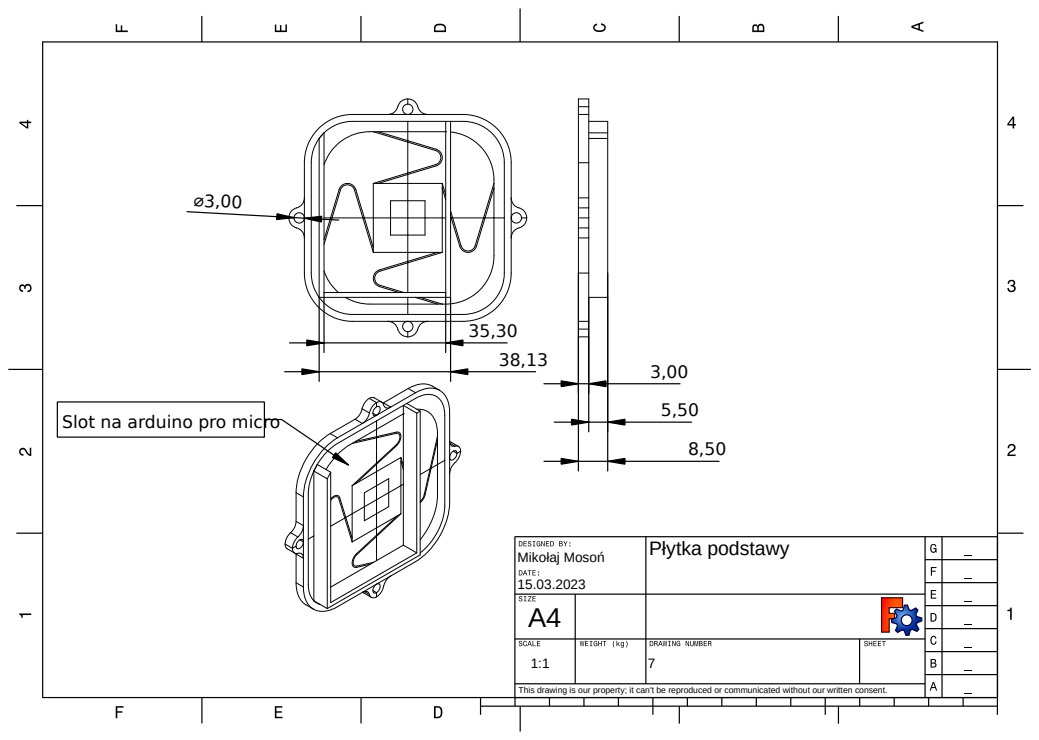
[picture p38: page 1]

Slot na arduino pro micro

Mikołaj Mosoń 15.03.2023 | Płytka podstawy

This drawing is our property; it can't be reproduced or communicated without our written consent.

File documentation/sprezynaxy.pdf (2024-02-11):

20,00
9,96

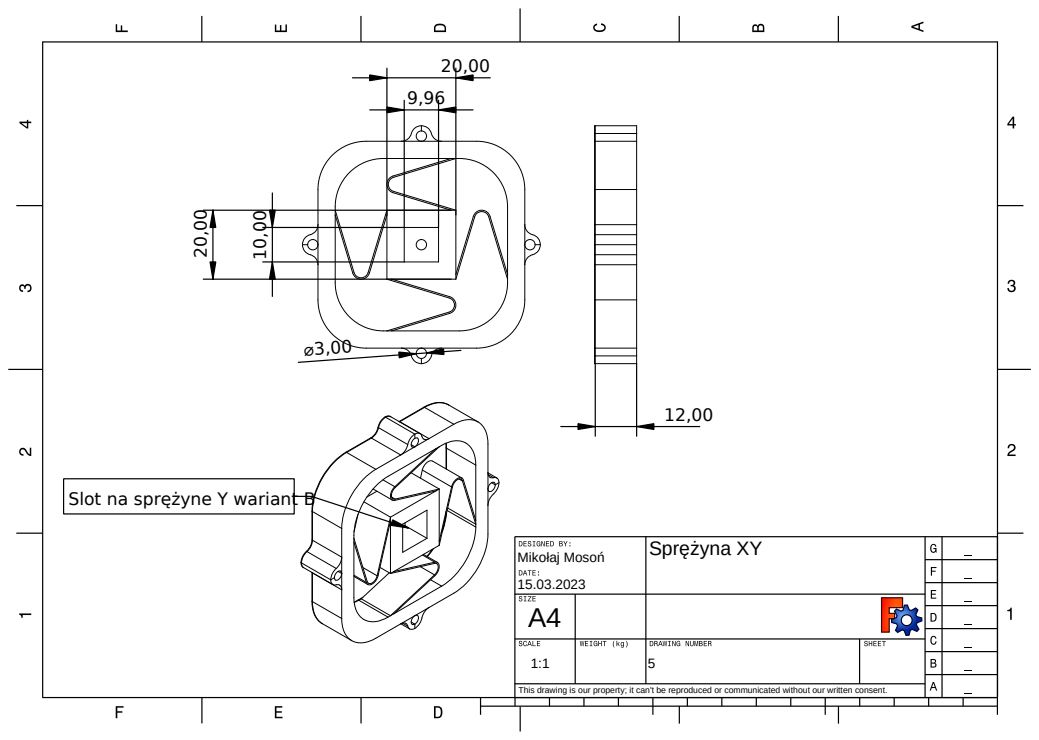
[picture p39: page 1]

Slot na sprężyne Y wariant B

Mikołaj Mosoń 15.03.2023 | Sprężyna XY

This drawing is our property; it can't be reproduced or communicated without our written consent.

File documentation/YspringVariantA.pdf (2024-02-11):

9,00

# Mocowanie na śruby M3

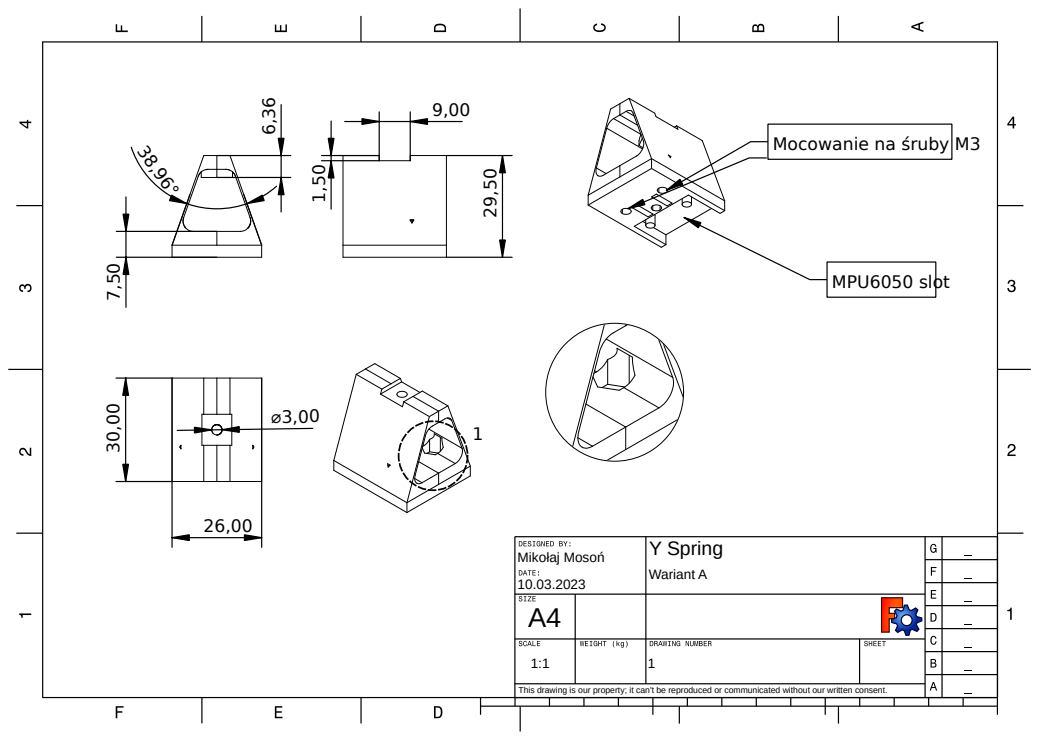
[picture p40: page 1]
MPU6050 slot

Mikołaj Mosoń 10.03.2023 | Y Spring Wariant A

This drawing is our property; it can't be reproduced or communicated without our written consent.

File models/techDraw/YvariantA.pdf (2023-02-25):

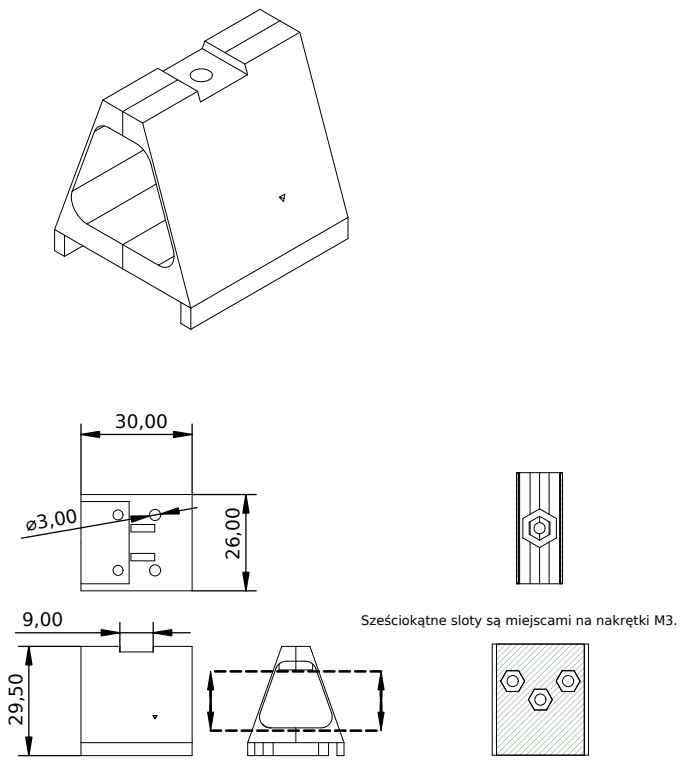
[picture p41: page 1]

Sześciokątne sloty są miejscami na nakrętki M3.

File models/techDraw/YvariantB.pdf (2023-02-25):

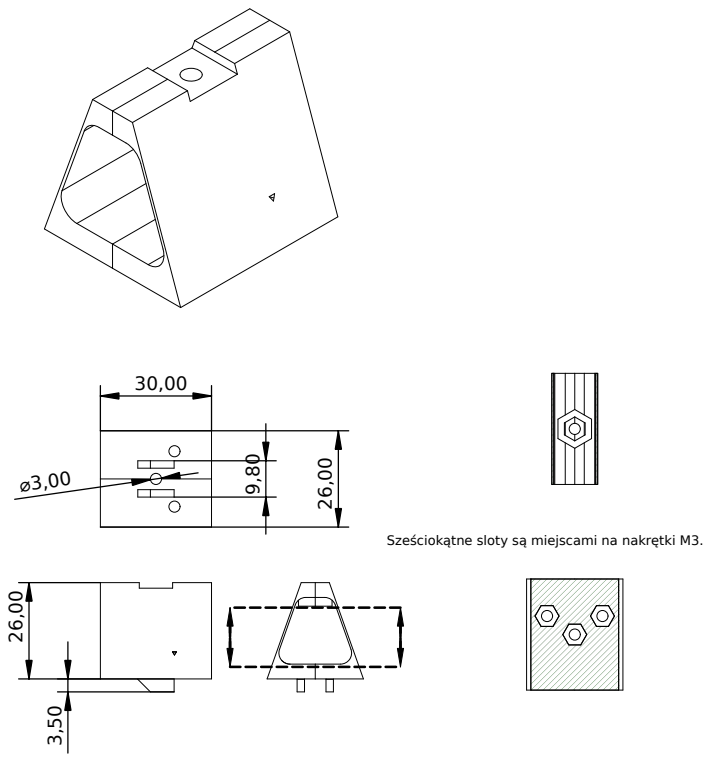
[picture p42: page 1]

Sześciokątne sloty są miejscami na nakrętki M3.

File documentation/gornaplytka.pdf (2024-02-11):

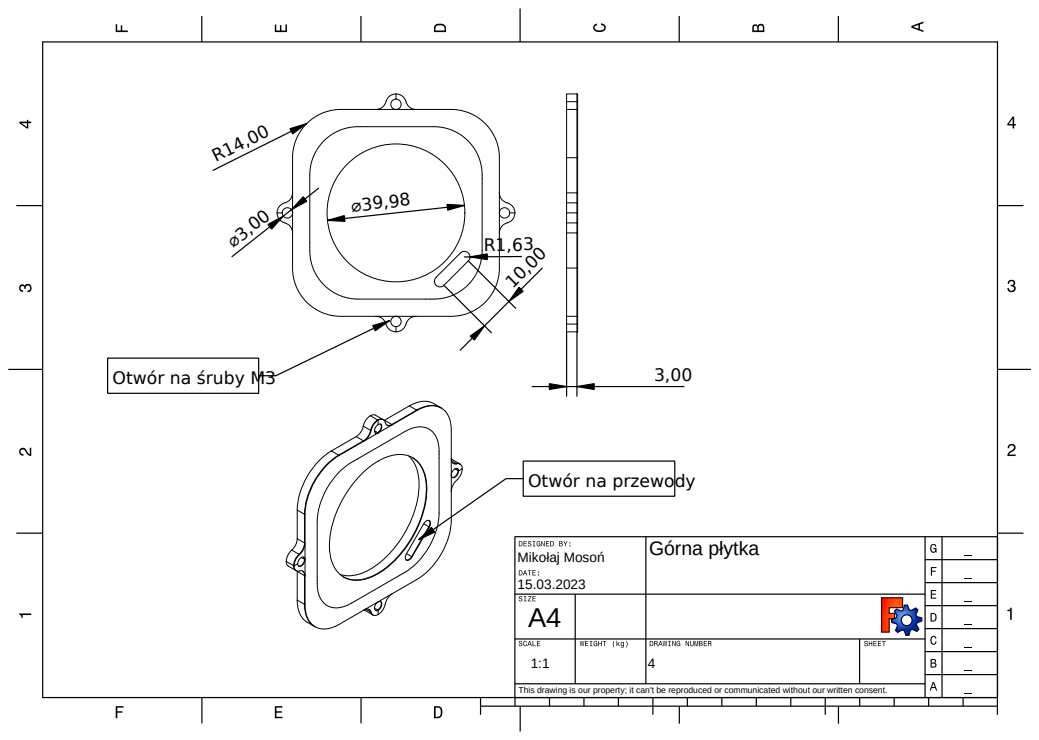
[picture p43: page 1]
Otwór na śruby M3

Otwór na przewody

Mikołaj Mosoń 15.03.2023 | Górna płytka

This drawing is our property; it can't be reproduced or communicated without our written consent.

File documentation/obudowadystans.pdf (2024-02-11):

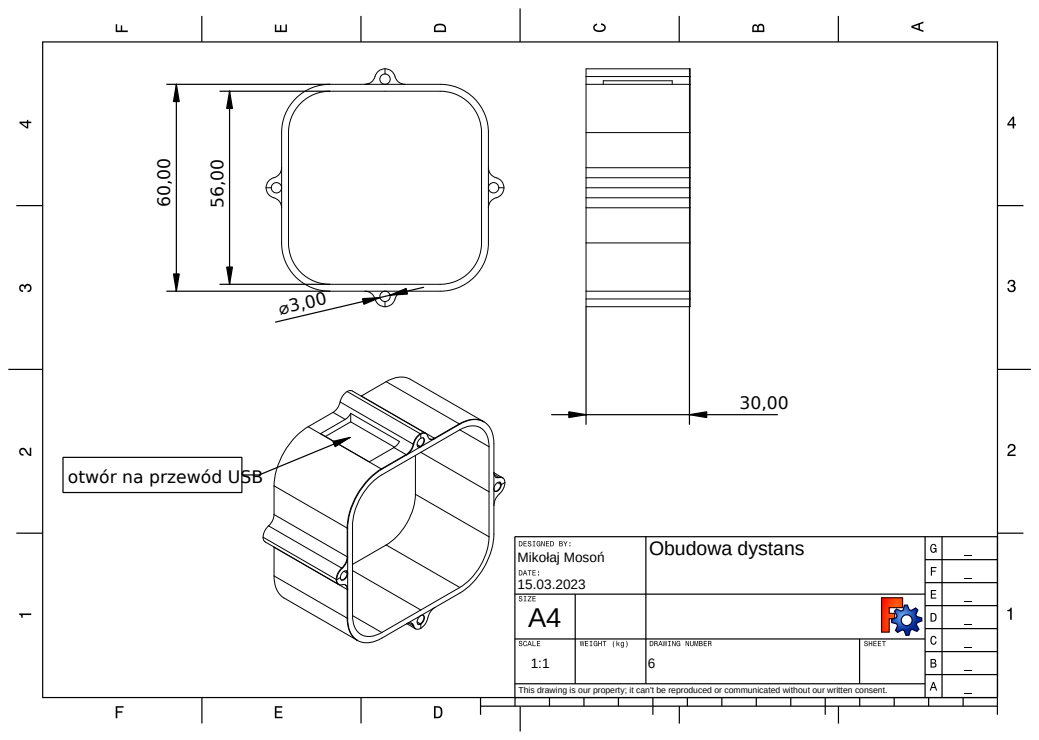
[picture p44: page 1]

otwór na przewód USB

Mikołaj Mosoń 15.03.2023 | Obudowa dystans

This drawing is our property; it can't be reproduced or communicated without our written consent.

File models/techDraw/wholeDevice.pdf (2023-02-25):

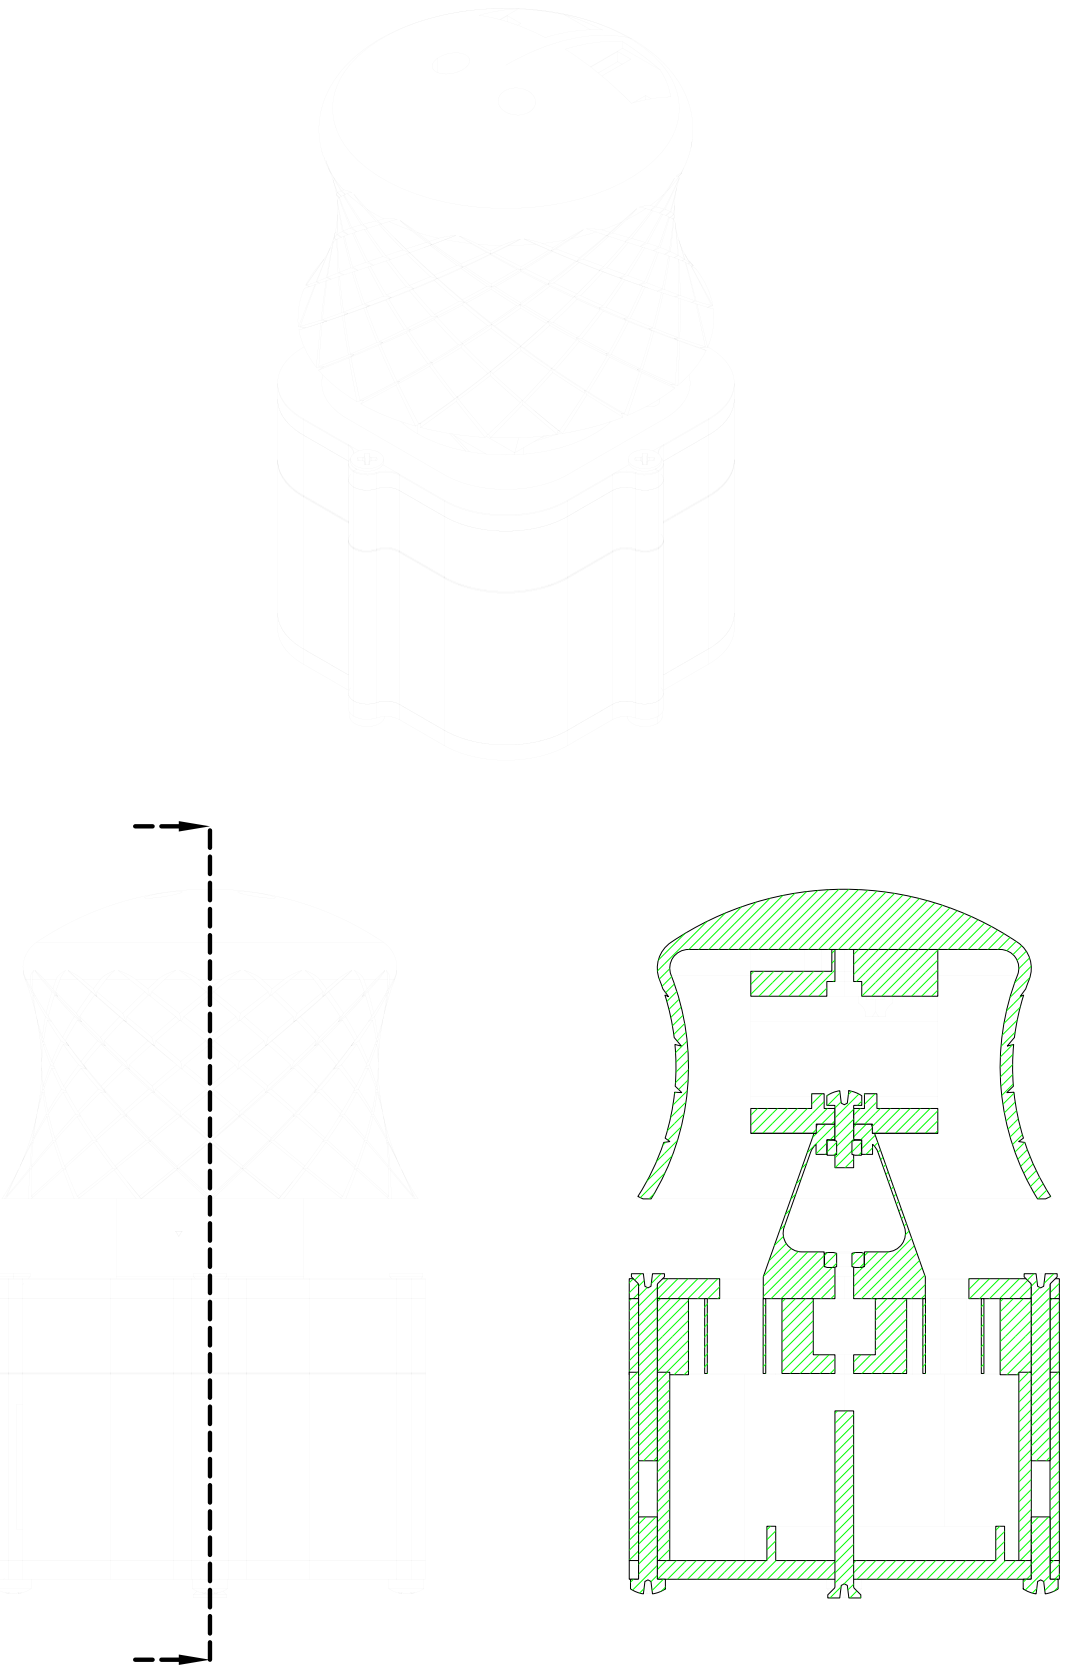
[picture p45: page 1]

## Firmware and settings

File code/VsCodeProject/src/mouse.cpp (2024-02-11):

#include <Arduino.h>
#include <MPU6050_6Axis_MotionApps612.h>
#include <Wire.h>
#include <ArduinoSTL.h>
#include <array>
#include <deque>
#include <pt.h>
#include <avr/wdt.h>

// #include <XInputAdapter.h>
// #include <XInput.h>
// XInputController x;
// JoystickEmulator &&joystick = XInputAdapter(x);

#include <JoystickLibraryAdapter.h>
Joystick_ j{0x06, JOYSTICK_TYPE_MULTI_AXIS, 0, 0, true, true, true, true, true, true, false, false, false, false, false};
JoystickEmulator &&joystick = JoystickLibraryAdapter(j);

float median(std::deque<float> &currentAxis)
{
  float min{currentAxis.at(0)};
  float max{currentAxis.at(0)};
  float sum{0};
  for (auto &val : currentAxis)
  {
    max = (val > max) ? val : max;
    min = (val < min) ? val : min;
    sum += val;
  }
  return sum - max - min;
}

// only axis










MPU6050 mpu;
// MPU control/status vars
constexpr long int I2C_CLOCK{400000};
constexpr long int BAUD{115200};
constexpr int MODE_BUTTON{7};
constexpr int BROADCAST_BUTTON{8};
constexpr int GREEN_PIN{A1};
constexpr int RED_PIN{A2};
constexpr int BLUE_PIN{A3};
enum CALIBRATION_DATA
{
  GYRO_X = -101,
  GYRO_Y = -48,
  GYRO_Z = 16,
  ACCEL_X = 1440,
  ACCEL_Y = 2110,
  ACCEL_Z = 1824,
};
enum AXIS_RANGE
{
  MIN_X = -2000,
  MAX_X = 2000,
  MIN_Y = -2000,
  MAX_Y = 2000,
  MIN_Z = -2000,
  MAX_Z = 2000,
};
enum TIMING
{
  // in ms
  SERIAL_THREAD_TIMER = 15,
  JOYSTICK_THREAD_TIMER = 5,
  MPU_THREAD_TIMER = 2,
  MODE_BUTTON_INTERRUPT_TIMER = 100,
  RGB_THREAD_TIMER = 2,
};
enum class Mode
{
  XYZ,
  rXrYrZ,
  BROADCASTING,
  NOT_BROADCASTING,
};

static pt printThread, joystickThread, mpuThread, rgbThread;

uint8_t devStatus;      // return status after each device operation (0 = success, !0 = error)
uint16_t packetSize;    // expected DMP packet size (default is 42 bytes)
uint16_t fifoCount;     // count of all bytes currently in FIFO
uint8_t fifoBuffer[64]; // FIFO storage buffer
Quaternion q;           // [w, x, y, z]         quaternion container
VectorFloat gravity;    // [x, y, z]            gravity vector
float ypr[3];           // [yaw, pitch, roll]   yaw/pitch/roll container and gravity vector
volatile Mode deviceMode{Mode::rXrYrZ};
volatile Mode broadcastMode{Mode::NOT_BROADCASTING};
typedef std::deque<float> axis;
std::array<axis, 3> allAxis;
std::array<float, 3> deviceValues;
std::array<int, 3> pinsRGB;

void deviceFailed(int code)
{
  // (if it's going to break, usually the code will be 1)
  // 1 = initial memory load failed
  // 2 = DMP configuration updates failed
  // 10 = Wrong mode detected
  while (1)
  {
    Serial.print(F("Device failed (code "));
    Serial.print(code);
    Serial.println(F(")"));
    delay(1000);
    analogWrite(RED_PIN, 255);
    delay(1000);
    analogWrite(RED_PIN, 0);
  }
}

void modeChange()
{
  static unsigned long last_interrupt_time = 0;
  if (millis() - last_interrupt_time > MODE_BUTTON_INTERRUPT_TIMER)
  {
    switch (deviceMode)
    {
    case Mode::XYZ:
      deviceMode = Mode::rXrYrZ;
      break;
    case Mode::rXrYrZ:
      deviceMode = Mode::XYZ;
      break;
    default:
      Serial.print("Wrong mode chceck: ");
      Serial.print(__LINE__);
      deviceFailed(10);
      break;
    }
    // need to reset axis
    for (int index = 0; index < 3; index++)
    {
      joystick.setXYZ(index, 0);
      joystick.setRXRYRZ(index, 0);
    }
  }
  last_interrupt_time = millis();
}

void deviceReady()
{
  Serial.print("Device ready ");
  for (int pinIndex; pinIndex < 3; pinIndex++)
  {
    analogWrite(pinsRGB.at(pinIndex), 255);
    delay(300);
    analogWrite(pinsRGB.at(pinIndex), 0);
  }
}

void rgbUpdate(int pinIndex, int value)
{
  analogWrite(pinsRGB.at(pinIndex), map(value, -2000, 2000, 0, 255));
}

static void protothreadPrintSerial(pt &protoThread, const std::array<float, 3> &deviceValues, volatile const Mode &deviceMode, volatile const Mode &broadcastMode)
{
  static unsigned long lastTimePrint = 0;
  PT_BEGIN(&protoThread);
  while (1)
  {
    lastTimePrint = millis();
    PT_WAIT_UNTIL(&protoThread, millis() - lastTimePrint > SERIAL_THREAD_TIMER);
    Serial.print(millis());
    Serial.print('\t');
    switch (broadcastMode)
    {
    case Mode::BROADCASTING:
      Serial.print("broadcasting");
      break;
    case Mode::NOT_BROADCASTING:
      Serial.print("not broadcasting");
      break;
    default:
      Serial.print("Wrong mode chceck: ");
      Serial.print(__LINE__);
      deviceFailed(10);
      break;
    }
    Serial.print('\t');
    switch (deviceMode)
    {
    case Mode::XYZ:
      Serial.print("XYZ");
      break;
    case Mode::rXrYrZ:
      Serial.print("rXrYrZ");
      break;
    default:
      Serial.print("Wrong mode chceck: ");
      Serial.print(__LINE__);
      deviceFailed(10);
      break;
    }
    Serial.print('\t');
    for (auto axisNumber = 0; axisNumber < 3; axisNumber++)
    {
      Serial.print(deviceValues.at(axisNumber) * 100);
      Serial.print('\t');
    }
    Serial.println();
    PT_END(&protoThread);
  }
}

static void protothreadJoystickBroadcast(pt &protoThread, const std::array<float, 3> &deviceValues, volatile const Mode &deviceMode, volatile const Mode &broadcastMode)
{
  static unsigned long JoystickBroadcast = 0;
  PT_BEGIN(&protoThread);
  while (1)
  {
    JoystickBroadcast = millis();
    PT_WAIT_UNTIL(&protoThread, millis() - JoystickBroadcast > JOYSTICK_THREAD_TIMER);
    switch (broadcastMode)
    {
    case Mode::BROADCASTING:
      for (int setterIndex{0}; setterIndex < 3; setterIndex++)
      {
        auto val = deviceValues.at(setterIndex) * 100;
        switch (deviceMode)
        {
        case Mode::XYZ:
          joystick.setXYZ(setterIndex, val);
          break;
        case Mode::rXrYrZ:
          joystick.setRXRYRZ(setterIndex, val);
          break;
        default:
          Serial.print("Wrong mode chceck: ");
          Serial.print(__LINE__);
          deviceFailed(10);
          break;
        }
        joystick.send();
      }
      break;
    case Mode::NOT_BROADCASTING:
      break;
    default:
      Serial.print("Wrong mode chceck: ");
      Serial.print(__LINE__);
      deviceFailed(10);
      break;
    }
  }
  PT_END(&protoThread);
}

static void protothreadRGB(pt &protoThread, const std::array<float, 3> &deviceValues, volatile const Mode &broadcastMode)
{
  static unsigned long rgbTimer = 0;
  PT_BEGIN(&protoThread);
  while (1)
  {
    rgbTimer = millis();
    PT_WAIT_UNTIL(&protoThread, millis() - rgbTimer > RGB_THREAD_TIMER);
    switch (broadcastMode)
    {
    case Mode::BROADCASTING:
      for (int pinIndex{0}; pinIndex < pinsRGB.size(); pinIndex++)
      {
        rgbUpdate(pinIndex, deviceValues.at(pinIndex));
      }
      break;
    case Mode::NOT_BROADCASTING:
      for (int pinIndex{0}; pinIndex < pinsRGB.size(); pinIndex++)
      {
        rgbUpdate(pinIndex, 0);
      }
      break;
    default:
      Serial.print("Wrong mode chceck: ");
      Serial.print(__LINE__);
      deviceFailed(10);
      break;
    }
  }
  PT_END(&protoThread);
}

static void protothreadMpuUpdate(pt &protoThread, std::array<float, 3> &deviceValues, volatile const Mode &broadcastMode)
{
  static unsigned long lastMpuUpdate = 0;
  static std::array<float, 3> offsets;
  PT_BEGIN(&protoThread);
  while (1)
  {
    lastMpuUpdate = millis();
    std::array<float, 3> filteredValues; // Mpu for one iteration sends max values
    // timing between 15 - 55 ms results in buffer error
    PT_WAIT_UNTIL(&protoThread, millis() - lastMpuUpdate > MPU_THREAD_TIMER);
    if (mpu.dmpGetCurrentFIFOPacket(fifoBuffer))
    {
      mpu.dmpGetQuaternion(&q, fifoBuffer);
      mpu.dmpGetGravity(&gravity, &q);
      mpu.dmpGetYawPitchRoll(ypr, &q, &gravity);
      for (int i = {0}; i < allAxis.size(); i++)
      {
        axis &currentAxis = allAxis.at(i);
        currentAxis.pop_front();
        currentAxis.push_back(ypr[i] * 180 / M_PI);
        filteredValues.at(i) = median(currentAxis);
      }
      if (broadcastMode == Mode::NOT_BROADCASTING)
      {
        offsets = {filteredValues};
      }
      for (int axisIndex{0}; axisIndex < deviceValues.size(); axisIndex++)
      {
        deviceValues.at(axisIndex) = {filteredValues.at(axisIndex) - offsets.at(axisIndex)};
      }
    }
  }
  PT_END(&protoThread);
}

void setup()
{
  Wire.begin();
  Wire.setClock(I2C_CLOCK); // 400kHz I2C clock. Comment this line if having compilation difficulties
  Serial.begin(BAUD);
  while (!Serial)
    ; // wait to open serial
  wdt_enable(WDTO_4S);
  Serial.println(F("Initializing I2C devices..."));
  mpu.initialize();
  devStatus = mpu.dmpInitialize();
  Serial.println(devStatus);
  if (devStatus != 0)
  {
    deviceFailed(devStatus);
  }
  mpu.setXGyroOffset(GYRO_X);
  mpu.setYGyroOffset(GYRO_Y);
  mpu.setZGyroOffset(GYRO_Z);

  mpu.setXAccelOffset(ACCEL_X);
  mpu.setYAccelOffset(ACCEL_Y);
  mpu.setZAccelOffset(ACCEL_Z);

  Serial.println(F("Enabling DMP..."));
  mpu.setDMPEnabled(true);
  packetSize = mpu.dmpGetFIFOPacketSize();
  // Braced initialiser does not work for deque
  for (auto &a : allAxis)
  {
    a.push_back(0);
    a.push_back(0);
    a.push_back(0);
  }

  pinMode(MODE_BUTTON, INPUT);                                              // todo lookup input pullup
  attachInterrupt(digitalPinToInterrupt(MODE_BUTTON), modeChange, FALLING); // trigger when button pressed, but not when released.
  pinMode(BROADCAST_BUTTON, INPUT_PULLUP);

  joystick.setXAxisRange(MIN_X, MAX_X);
  joystick.setYAxisRange(MIN_Y, MAX_Y);
  joystick.setZAxisRange(MIN_Z, MAX_Z);

  joystick.setRxAxisRange(MIN_X, MAX_X);
  joystick.setRyAxisRange(MIN_Y, MAX_Y);
  joystick.setRzAxisRange(MIN_Z, MAX_Z);

  pinsRGB.at(0) = {RED_PIN};
  pinsRGB.at(1) = {GREEN_PIN};
  pinsRGB.at(2) = {BLUE_PIN};

  PT_INIT(&printThread);
  PT_INIT(&joystickThread);
  PT_INIT(&mpuThread);
  PT_INIT(&rgbThread);

  deviceReady(); // device flashes RGB to signal its ready
}

void loop()
{
  wdt_reset();
  broadcastMode = (digitalRead(BROADCAST_BUTTON)) ? Mode::NOT_BROADCASTING : Mode::BROADCASTING;
  protothreadMpuUpdate(mpuThread, deviceValues, broadcastMode);
  protothreadJoystickBroadcast(joystickThread, deviceValues, deviceMode, broadcastMode);
  protothreadPrintSerial(printThread, deviceValues, deviceMode, broadcastMode);
  protothreadRGB(rgbThread, deviceValues, broadcastMode);
}

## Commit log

2022-03-31 added models for glove, X spring, Ortho–Planar Spring, created project in Clion
    [arduinoGlove-BottomPad002.stl, arduinoGlove-TopPad.stl, arduinoGlove-spacerPocket001.stl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]
2022-03-31 fixed X spring now parametric model does not break with different height and width values, fixed parameter name in X spreadsheet
    [mouse.FCStd]
2022-03-31 added Y spring, fixed all spreadsheet to use mm by default
    [mouse.FCStd]
2022-04-01 added XY stage it's not yet fully parametric
    [mouse.FCStd]
2022-04-01 XY stage is now fully parametric
    [mouse.FCStd]
2022-04-02 Created folder for stl, exported all models into stl format
    [arduinoGloveBottomPad.stl, arduinoGloveSpacer.stl, arduinoGloveTopPad.stl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]
2022-04-02 added Multiple Stage Platform, not fully finished
    [mouse.FCStd]
2022-05-12 addet base thickness to X spring
2022-05-12 added X plates for alternate design
2022-05-15 added X spring with space for gyro
    [mouseXspring.stl]
2022-05-15 added X spring hole clip
2022-06-12 Created Arduino Dummy and Serial Dummy
2022-06-18 Moved SerialDummy.h content into ArduinoDummy.h
2022-06-18 updated XYstage
    [mouseXYStage.stl, mouseXspringHoleClip.stl, mouseXspringWithHole.stl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]
2022-12-11 added knob model
    [mouse-Knob.stl, mouse.FCStd]
2022-12-12 added chamfer to knob
    [mouse.FCStd]
2022-12-12 added slots for m3 bolts in X spring
    [mouse.FCStd, mouseXspring.stl]
2022-12-12 added slots for m3 in Y spring
    [mouse.FCStd, mouseXspring.stl]
2023-01-16 Y spring change
    [mouse.FCStd]
2023-01-16 Y slot now has accelerometer slot
    [mouse.FCStd]
2023-01-20 Y spring with mpu to the side
    [encoderholder.stl, mouse-Knob.stl, mouse-Y bottom.stl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]
2023-01-31 added assembly
    [mouse-XY plate.stl, mouse-Y bottom.stl, mouse-breadboard plate.stl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]
2023-02-01 tech draw from assembly
    [mouseAssembly.FCStd]
2023-02-01 imported project from Arduino IDE
2023-02-08 removed some files
    [mouseAssembly.FCStd]
2023-02-09 threads refactor
2023-02-09 joystick thread now uses array of pointers to set XYZ rXrYrZ, joystick thread also updates rgb lights
2023-02-25 changed IDE, added mocks for Joystick_, added tests for JoystickAdapter
    [mouseAssembly.FCStd, wholeDevice.dxf]
2023-03-01 Removed ArduinoSTL from JoystickLibraryAdapter
2024-02-11 last commit hopefully
    [mouse-Y spring simple.stl, mouseAssembly.FCStd, wholeDevice.dxf]
